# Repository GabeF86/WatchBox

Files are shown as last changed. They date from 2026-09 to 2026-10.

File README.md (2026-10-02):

# WatchBox v0

A prototype watch case that shows your collection's market value on a 16×2 LCD.
A local web app stores your watches and values each one with the Apify valuation engine (eBay sold prices from the last 90 days plus Chrono24 asking prices), falling back to TheWatchAPI or eBay asking prices, and an ESP32 displays them.

## Hardware you need
- ESP32 devkit, I2C LCD1602 (PCF8574 backpack), USB cable and charger
- 4 female-female Dupont jumpers
- LCD: 4× M3 (or M2.5) self-tapping screws, **6 mm max** (longer ones can crack the front face)
- Back plate: 4× M3 × 10–12 mm self-tapping screws
- Double-sided foam tape for the ESP32

## Get a price source key
**Apify valuation engine (default, most accurate):** create a free account at https://apify.com, copy your Personal API token (Console → Settings → API & Integrations) into `server/.env` as `APIFY_TOKEN`. Each watch is valued from eBay sold listings (last 90 days) and Chrono24 asking prices, adjusted for its condition, box & papers and other details, with a backtest that shows how accurate the estimate is. Explain any watch's number by running `.venv/bin/python scripts/check_valuation.py <watch id>` from `server/` (add `--fetch` to pull fresh data first).
After switching to the Apify engine, click **Refresh prices now** once to get the first valuations right away; otherwise they wait for the next scheduled refresh.

**TheWatchAPI (fallback):** register free at https://www.thewatchapi.com/register and put your API token in `server/.env` as `THEWATCHAPI_TOKEN`.
The free plan allows 25 requests a day, so keep `REFRESH_HOURS=24` (8 watches = 8 requests a day, plus one per watch you add or edit).
Their docs say price history may need the Standard plan; if so, the app logs a clear "may need a higher TheWatchAPI plan" error. Check with `scripts/check_price.py` right after you get your token.

**eBay (optional fallback):** used if both `APIFY_TOKEN` and `THEWATCHAPI_TOKEN` are empty.
1. Sign up at https://developer.ebay.com and create a **Production** keyset.
2. When asked about Marketplace Account Deletion notifications, choose the opt-out/exempt option (this app stores no eBay user data).
3. Copy **App ID** → `EBAY_CLIENT_ID` and **Cert ID** → `EBAY_CLIENT_SECRET` in `server/.env`.

## Run the app
```bash
cd server
python3 -m venv .venv && .venv/bin/pip install -r requirements.txt
cp .env.example .env        # add your APIFY_TOKEN (or THEWATCHAPI_TOKEN)
.venv/bin/python -m watchbox
```
Open http://localhost:8000 and add watches. The log prints the `ESP32 SERVER_URL` to put in the firmware config.
On first run macOS asks whether Python may accept incoming network connections: click **Allow**, or the ESP32 can't reach the server.

Check one price by hand: `.venv/bin/python scripts/check_price.py Rolex 126610LN`
Tests: `.venv/bin/pytest -q`

Backups: the database uses SQLite WAL mode, so don't just copy `watchbox.db` while the app is running. Either run `sqlite3 server/watchbox.db ".backup watchbox-backup.db"` (safe while running), or stop the app and copy `watchbox.db` together with its `watchbox.db-wal` and `watchbox.db-shm` files.

## Flash the ESP32
Install arduino-cli (no Homebrew needed) and the ESP32 core once:
```bash
mkdir -p ~/.local/bin && curl -fsSL https://downloads.arduino.cc/arduino-cli/arduino-cli_latest_macOS_ARM64.tar.gz | tar -xz -C ~/.local/bin arduino-cli
alias arduino-cli=~/.local/bin/arduino-cli      # or add ~/.local/bin to PATH
arduino-cli config init --overwrite
arduino-cli config add board_manager.additional_urls https://espressif.github.io/arduino-esp32/package_esp32_index.json
arduino-cli core update-index && arduino-cli core install esp32:esp32
arduino-cli lib install "LiquidCrystal I2C" ArduinoJson
```

Wiring: LCD GND→GND, VCC→5V (labelled VIN on some boards), SDA→GPIO21, SCL→GPIO22. Optional button: GPIO4→GND.
```bash
cp firmware/watchbox_v0/config.example.h firmware/watchbox_v0/config.h   # edit Wi-Fi (2.4 GHz), SERVER_URL, LCD_ADDR
arduino-cli board list                                                    # find the port, e.g. /dev/cu.usbserial-0001
arduino-cli compile --upload -p <port> --fqbn esp32:esp32:esp32 firmware/watchbox_v0
arduino-cli monitor -p <port> -c baudrate=115200
```
Don't know the LCD address? Flash `firmware/i2c_scan` first and watch the serial monitor.

Hardware notes:
- Backlight on but no text: turn the blue contrast potentiometer on the LCD backpack.
- A backpack powered from 5V pulls SDA/SCL up to 5V, but ESP32 pins are 3.3V. It usually works but is out of spec. For a long-running build, power the backpack from 3.3V (re-adjust the contrast pot) or use an I2C level shifter.
- If the LCD shows garbage or the board resets when Wi-Fi starts, the USB supply is too weak: use a better cable or charger.

## Print the enclosure
Download OpenSCAD from https://openscad.org/downloads.html (the macOS development snapshot works on Apple Silicon) and drag it to `/Applications` or `~/Applications`. Edit the measurements at the top of `enclosure/watchbox_v0.scad`, then:
```bash
alias openscad="$HOME/Applications/OpenSCAD.app/Contents/MacOS/OpenSCAD"   # or /Applications/...
openscad -D 'part="front"' -o enclosure/watchbox_v0_front.stl enclosure/watchbox_v0.scad
openscad -D 'part="back"'  -o enclosure/watchbox_v0_back.stl  enclosure/watchbox_v0.scad
```
Front shell face-down, back plate flat with the rail up, no supports. In Bambu Studio, turn on elephant-foot compensation: the front face is the first layer and the window must stay full size.

Before mounting the LCD: the common PCF8574 backpack's 4 header pins stick out sideways past the LCD's short edge and won't fit in the box. Gently bend them 90° toward the back (or solder the wires on directly).
Stick the ESP32 to the rail with its USB end toward the right wall (the USB notch). When closing the box, the tall stop at the rail's other end must point away from the notch.

## Notes
**Apify valuation engine:** each estimate comes from eBay sold prices (last 90 days) blended with Chrono24 asking prices, which are first lowered by the measured asking-to-sold gap. Both are adjusted for your watch's condition and box & papers. The web page shows the breakdown, the confidence and a backtest. On the LCD, a `?` after the price means low confidence. Run `.venv/bin/python scripts/check_valuation.py <watch id>` from `server/` to see every comparable and why it was kept or dropped.

**TheWatchAPI / eBay Browse fallbacks:** these are **asking** prices, not sold prices. TheWatchAPI's data can lag (in Sept 2026 its newest point was 2024-07-17), so the page shows the data date, and the LCD adds the month (e.g. `$12,413 Jul24`) when the data is over 30 days old. The price is TheWatchAPI's latest indicative USD price for the reference number, or (eBay fallback) the median of current eBay listings.

If your exact reference isn't listed, fill in "Price using reference" with a close variant; the price is then marked as an estimate (`~` on the LCD).
The price source is swappable (`server/watchbox/pricing.py` → `PriceProvider`; the engine is `server/watchbox/valuation/`).

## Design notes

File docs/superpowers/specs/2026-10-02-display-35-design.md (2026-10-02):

# WatchBox v1, Part 3: 3.5" Display Firmware: Design

**Date:** 2026-10-02
**Status:** Approved in brainstorming, awaiting spec review
**Builds on:** `2026-10-02-valuation-engine-design.md` (part 1), the server in `server/`, and the bring-up sketch `firmware/board_test_35/`.

## Context

The box's screen is an **ESP32-32E 3.5" board** (LCDwiki/Elecrow E32R35T):
- **Display:** ST7796 panel, 320×480, used in landscape at 480×320.
- **Touch:** XPT2046 resistive, sharing the HSPI bus (SCK 14, MOSI 13, MISO 12); LCD CS 15, DC 2, backlight 27; touch CS 33, touch interrupt 36.
- **Other hardware:** battery sense on ADC 34, and BOOT on IO0.
- **Mounting:** the board sits in the printed lid liner (`enclosure/lid_liner.scad`), behind its window.

Bring-up on 2026-10-02 established the following, which are now requirements:
- **SPI write clock 20 MHz.** At 40 MHz the colors came out garbled.
- **Normal colors:** inversion off, RGB order.
- **Touch calibration** `{378, 3815, 333, 301, 3689, 3781, 3687, 332}`, used with `setRotation(1)`.
- **The LovyanGFX library works.** The bring-up sketch used about 84% of the default 1.3 MB app partition.

## Decisions made in brainstorming

| Topic | Decision |
|---|---|
| Home screen | **A:** large gold total at the top, then a 4 × 2 slot map laid out like the insert |
| Detail screen | **A:** large estimate and confidence, then three figures: eBay sold, Chrono24 asking, accuracy |
| Setup | **A:** box hotspot + QR setup page now; account pairing comes with part 2 |
| Power | **A:** sleep after inactivity, wake on touch; no lid switch for now |
| Rendering | Draw directly with LovyanGFX (no LVGL, no server-rendered images) |

## Goals

1. Show the collection on the 3.5" screen as a slot map with per-watch detail screens, using the valuation engine's data.
2. Let a new owner set up Wi-Fi and the app address from a phone, with no reflashing.
3. Last for days on battery: deep sleep when not in use, and an instant display of cached data on wake.

## Non-goals

Account pairing and QR pairing to an account (part 2), slot presence sensors, a lid switch, price-trend charts, OTA updates, and controls on the box for editing watches.

## 1. Server: `GET /api/box`

The response contains structured data for the 3.5" box. `/api/display` stays unchanged for the 16×2 LCD box.

```json
{
  "generated_at": "2026-10-02T14:00:00+00:00",
  "total_usd": 39130,
  "priced": 4,
  "slots": [
    {"slot": 1, "watch": {
      "id": 1, "name": "Portugieser", "brand": "IWC", "model": "Portugieser Chronograph",
      "reference": "IW371615", "details": "Full set · Excellent",
      "estimate_usd": 6940, "estimated_reference": false, "confidence": "medium",
      "ebay": {"n": 0, "median": null, "p10": null, "p90": null},
      "chrono24": {"n": 37, "median": 6308},
      "accuracy": {"n": 0, "mdape": null},
      "as_of": "2026-10-02T09:14:00+00:00"}},
    {"slot": 5, "watch": null}
  ],
  "unslotted": []
}
```

- **`slots`** always has exactly 8 entries, ordered 1–8. An empty slot has `"watch": null`. Watches without a slot go in `unslotted`, using the same object shape.
- **`name`** is the nickname if set, otherwise the model, as plain text.
- **`details`** is "<box & papers label> · <condition label>", built with the existing `valuation.models.label()`.
- **`reference`** is the watch's own reference. `estimated_reference` is true when `price_reference` is set; the box then prefixes the price with "~".
- **Valuation fields** come from the latest valuation (`db.latest_valuations`). A watch with no valuation, but a v0 price (TheWatchAPI or eBay Browse), reports that price with `confidence: null` and empty eBay, Chrono24 and accuracy blocks. A watch with no price at all has `estimate_usd: null`.
- **`total_usd`** sums the estimates that are present, and **`priced`** counts them. All money values are whole-dollar integers, so the firmware doesn't format decimals.
- Implemented as a pure builder function `build_box_payload(watches, valuations)` in `server/watchbox/box.py`, plus a route in `app.py`.

## 2. Firmware layout: `firmware/watchbox_35/`

| File | Responsibility |
|---|---|
| `watchbox_35.ino` | Entry point, main loop, the screen state machine |
| `board.h` | LovyanGFX device class (pins, 20 MHz, colors, touch calibration) |
| `theme.h` | Colors, fonts, layout constants |
| `data.h/.cpp` | Box data model; fetching `/api/box`; parsing; caching in NVS |
| `screens.h/.cpp` | Drawing: status bar, home, detail, settings, setup, messages |
| `input.h/.cpp` | Touch handling: tap / swipe detection, hit-testing tiles and buttons |
| `power.h/.cpp` | Battery reading, backlight dimming, deep sleep and wake |
| `net.h/.cpp` | Wi-Fi with WiFiManager, the hotspot, settings stored in NVS |

- **Board settings:** `esp32:esp32:esp32` with **`PartitionScheme=huge_app`** (3 MB app, no OTA).
- **Libraries:** LovyanGFX, ArduinoJson 7, WiFiManager (tzapu).
- `config.h` is no longer used.

## 3. Screens (480 × 320, landscape)

**Theme**

| Element | Value |
|---|---|
| Background | #0B0C0E |
| Tile | #16191E |
| Text | #E9E9E9 |
| Muted text | #8B9099 |
| Gold (total, estimates) | #F2C46D |
| Confidence dots | high #5FD18B, medium #E7C160, low #E07A6A, no confidence grey |

Fonts are LovyanGFX FreeSans and FreeSansBold at 9/12/18/24 pt.

**Status bar** (24 px, every screen except setup)
- Left: the title or "‹ Back".
- Right: Wi-Fi indicator (●, or ○ when offline), battery ("82%" or "USB"), "updated h:mm", and a ⚙ icon (tap target 40×24).

**Home**
- **Total row:** the total in gold 24 pt at the left; "N watches · market estimate" muted on the right.
- **Slot map:** a 4 × 2 grid of tiles (about 110 × 100 px, 6 px gaps).
  - A tile with a watch shows the slot number (muted), its name (12 pt, up to 2 lines, ending in "…" if it doesn't fit), and the price (FreeSansBold 12 pt) with its confidence dot.
  - An empty slot is a dashed outline with "Empty".
  - A watch with no price shows "no price yet".
- **Tapping a watch tile** opens its detail screen; tapping an empty tile does nothing.
- **Unslotted watches** count toward the total but have no tile; the settings screen shows how many there are.

**Detail**
- **Status bar:** "‹ Back" on the left, "Slot N of 8" on the right.
- **Body:**
  - A muted line: BRAND · REFERENCE · details.
  - The name (18 pt).
  - The estimate (gold 24 pt bold, "~" prefix if estimated from another reference) plus the confidence dot and word.
  - Three columns:

    | Column | Main figure | Second line |
    |---|---|---|
    | eBay sold · 90 d | median | "N sales · $Xk–$Yk" (p10–p90) |
    | Chrono24 asking | median | "N listings" |
    | Accuracy | "±Z%" | "backtest, N sales" |

  - A column with no data shows "—" and "not enough data".
  - Footer (muted): "Updated <date time> · eBay + Chrono24".
- **Swiping left or right** moves to the next or previous slot that has a watch, wrapping around. Tapping Back, or **30 s with no touch**, returns home.

**Settings (⚙)**
- **Left:** a QR code, 150 px, encoding the app URL, with the label "Open the app on your phone".
- **Right:** Wi-Fi SSID and signal (dBm), app address, battery voltage and %, firmware version, and the count of unslotted watches if there are any.
- **Buttons:**
  - **Re-run setup:** asks for confirmation, then clears the Wi-Fi settings and restarts into setup.
  - **Back.**

**Setup** (no status bar)
- **Title:** "Set up your WatchBox".
- **Left:** a Wi-Fi QR code (`WIFI:T:nopass;S:WatchBox-XXXX;;`). XXXX is the last 4 hex digits of the MAC address.
- **Right:** the steps:
  1. Scan to join WatchBox-XXXX.
  2. The setup page opens. If it doesn't, go to 192.168.4.1.
  3. Choose your Wi-Fi, enter the app address, then save.

**Messages** (a banner under the status bar, or a full screen)
- **Offline:** "Can't reach the app — showing values from <time>". The cached data stays visible.
- **No data yet** (first boot after setup, app unreachable): "Waiting for the app at <url>…".
- **Low battery** (below 10%, on battery power): "Battery low — please charge".

## 4. Setup and network

- **WiFiManager handles the hotspot.**
  - The hotspot is open, named `WatchBox-XXXX`, with a captive portal.
  - The portal has a custom field "App address" (default `http://watchbox.local:8000`, placeholder `http://192.168.1.50:8000`).
  - The portal times out after 10 minutes, then the box restarts and tries again.
- **Storage:** the app address is saved in NVS (`Preferences` namespace `watchbox`, key `server`). WiFiManager stores the Wi-Fi credentials itself.
- **On boot:**
  - With no saved Wi-Fi, the box shows the setup screen and starts the portal. The setup screen is drawn from WiFiManager's AP-mode callback.
  - Otherwise it connects in the background, waiting up to 20 s. If that fails, it falls back to the cached data plus the offline banner, and keeps retrying every 30 s.
  - **Setup starts only on a first boot or "Re-run setup".** A temporary Wi-Fi outage must not drop a configured box into setup.
- **Fetching:** while awake, the box gets `GET <server>/api/box` on wake and then every 60 s.
  - It uses HTTP/1.0, a 3 s connect timeout and a 5 s read timeout.
  - It validates the payload: `slots` must be an array of 8.
  - It caches the raw JSON in NVS (`Preferences` key `box`, up to 6 KB) only after a successful parse.

## 5. Power

- **Dimming and sleep:** after **120 s** with no touch, the backlight dims to 15%. After **15 s more**, the box saves the current screen state and enters **deep sleep** with `esp_sleep_enable_ext0_wakeup(GPIO_NUM_36, 0)`; the XPT2046 interrupt goes low on touch. The backlight is off and Wi-Fi is stopped first.
- **On wake:**
  1. Draw home from the NVS cache in under 1 s.
  2. Connect Wi-Fi and fetch.
  3. Redraw when the new data differs.
  4. The touch that woke the box isn't treated as a tap.
- **Battery:**
  - The voltage is read as `analogReadMilliVolts(34) × 2`. This assumes the board's 1:2 divider; verify it against a multimeter during bring-up.
  - Conversion to %: linear from 3.30 V (0%) to 4.15 V (100%), clamped.
  - A reading under 2.5 V or over 4.5 V means "USB" (no battery fitted or charging artefacts).
  - Below 10% on battery shows the low-battery banner.
- **Plugged-in mode:** with no battery reading (USB), the sleep timer is **10 min** instead of 2 min.

## 6. Error handling

| Situation | Behaviour |
|---|---|
| App unreachable / HTTP error / bad JSON | Keep the cached data; offline banner with the cache time; retry next cycle |
| No cache and no app | "Waiting for the app at <url>…" |
| Wi-Fi lost while awake | ○ icon, auto-reconnect, offline banner after a failed fetch |
| Touch on an empty tile or outside targets | Ignored |
| Name too long for a tile | Wrapped to 2 lines, then "…" |
| NVS write fails | Logged to serial; the display is unaffected |

## 7. Testing

- **Server:** pytest tests for `build_box_payload` and `/api/box`:
  - always 8 slots;
  - empty slots;
  - unslotted watches;
  - a valuation-backed watch with all blocks;
  - a v0-price fallback;
  - no price at all;
  - the estimated-reference flag;
  - totals and integer rounding.
- **Firmware:** must compile with no warnings from our code. A small `formatPrice` / `truncate` helper set lives in a header with no hardware dependencies.
- **Hands-on acceptance on the owner's board:**
  1. Fresh setup through the hotspot from a phone.
  2. The home screen shows all 4 watches and empty slots 5–8.
  3. Tapping a tile opens its detail.
  4. Swiping moves between watches.
  5. The screen returns home after 30 s.
  6. Settings shows the QR code, and it opens the app.
  7. With the Mac app stopped, the offline banner shows with cached values.
  8. After 2 minutes the screen dims and the box sleeps; a touch wakes it with an instant cached display.
  9. "Re-run setup" works.

## Known limitations

- **Battery calibration:** the divider ratio is assumed and must be checked once.
- **Lid detection:** with no lid switch, the box sleeps on inactivity and not when the lid closes.
- **"watchbox.local" default:** the default app address assumes the Mac app is reachable by that name. Until mDNS is added to the server, the owner enters the Mac's IP address on the setup page.

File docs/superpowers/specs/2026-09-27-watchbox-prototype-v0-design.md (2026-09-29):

# Watch Box Prototype v0: Design

> **Update 2026-09-28:** TheWatchAPI (thewatchapi.com) is now the default price source. See "Price source: TheWatchAPI" at the end. The eBay provider below stays as a fallback. The default refresh is now every 24 h to fit TheWatchAPI's free plan (25 requests a day).

**Date:** 2026-09-27
**Status:** Approved (brainstorming), awaiting spec review

## Context

The long-term product is a smart watch case: a 3D-printed heavy-duty case (about 250 × 205 mm) with an 8-slot insert (4 × 2 grid, slots about 55 × 85 mm, 42 mm deep). A 3.5" color screen inside the lid shows the live market value of the watches currently in the box. Each slot has a presence sensor, owners assign watches to numbered slots on a mobile-friendly website, and a watch's value counts only while its slot detects it. The box runs on a built-in LiPo with USB-C charging, pairs through a setup hotspot and a 6-digit code, and fetches ready-made screen data from a server. The server pulls prices from a licensed provider (WatchCharts) through a swappable price-provider layer.

**v0 is a much smaller first step** that proves the core loop with parts already on hand:
enter watches → fetch real market prices → show them on a screen in the box.

## Goals

1. Enter watches (brand, model, reference, slot 1–8, optional nickname) in a local web app.
2. Fetch a market price per watch from the eBay Browse API automatically.
3. Show the total and each watch's price on the kit's 16×2 I2C LCD, driven by the kit's ESP32.
4. House the ESP32 and LCD in a 3D-printed standalone enclosure (Bambu Studio).

## Non-goals (v0)

Slot presence sensors, battery power, the 3.5" color screen, user accounts or login, cloud hosting, pairing flow, lid-mounted panel, WatchCharts integration.

## Architecture

```
┌──────────────── Mac (same Wi-Fi) ────────────────┐        ┌──── ESP32 + LCD1602 ────┐
│  FastAPI app  ──  SQLite (watches, prices)       │        │  every 60 s:            │
│   ├─ web UI: add/edit/delete watches             │◄───────┤  GET /api/display       │
│   ├─ scheduler: refresh prices every 6 h         │  JSON  │  cycle lines every 4 s  │
│   └─ PriceProvider ── EbayBrowseProvider ──► eBay│        └─────────────────────────┘
└──────────────────────────────────────────────────┘
```

The box asks the server for ready-to-show data, and the server owns all logic and secrets. This matches the final product's architecture, so moving the server to the cloud later is a deployment change.

## Components

### 1. Server app (`server/`): Python 3.13, FastAPI, SQLite

**Data model**
- `watches`: id, brand, model, reference, slot (1–8, unique, nullable), nickname (nullable), created_at
- `prices`: id, watch_id, price_usd (numeric), sample_size (int), source (`"ebay"`), fetched_at. History is kept, and the latest row is the current price.

**Web UI** (server-rendered HTML, mobile-friendly, no JS framework)
- List of watches: slot, display name, current price, "fetched X ago", sample size.
- Add/edit form and delete button.
- "Refresh prices now" button.
- Collection total at the top.

**Price provider layer**
- Interface: `PriceProvider.get_price(brand, reference) -> PriceResult | None`, where `PriceResult` holds `price_usd`, `sample_size` and `source`.
- `EbayBrowseProvider`:
  - Authenticates with an OAuth client-credentials token (scope `https://api.ebay.com/oauth/api_scope`), cached until it expires.
  - Calls `GET /buy/browse/v1/item_summary/search` with `q="<brand> <reference>"`, `category_ids=31387` (Wristwatches), `filter=buyingOptions:{FIXED_PRICE},price:[500..],priceCurrency:USD`, `limit=100`.
  - Keeps only listings whose title contains the reference number, ignoring case, spaces and punctuation (so `126610 LN` matches `126610LN`).
  - Drops titles containing junk phrases (`box only`, `papers only`, `empty box`, `strap only`, `bracelet only`, `band only`, `links only`, `dial only`, `bezel only`, `bezel insert`, `crown only`, `case back`, `for parts`, `parts only`, `for repair`, `needs repair`, `repair only`, `homage`, `replica`, `instruction manual`, `manual only`, `booklet`). These are phrases, not single words, so normal titles like "Ceramic Bezel", "Oyster bracelet", or "Manual Wind" are kept.
  - Editing a watch's brand or reference clears its price history, so a stale price for the old reference is never shown.
  - Removes outliers outside [0.5 × median, 2 × median] of the remaining prices, then returns the median of what's left.
  - Returns `None` when fewer than 3 listings survive, and the UI shows "no price yet" (the server log records why).
- Only `USD` prices are used, and the value is the median **asking** price, labeled as such in the UI.

**Scheduler**
- Refreshes all watches on startup if the newest price is older than 6 h, then every 6 h (APScheduler or an asyncio loop).
- A new or edited watch is priced immediately.
- On eBay errors: log, keep the last good price, and retry at the next cycle.

**Display endpoint:** `GET /api/display`
```json
{
  "generated_at": "2026-09-27T14:00:00Z",
  "screens": [
    {"line1": "TOTAL 7 watches", "line2": "$84,250"},
    {"line1": "1 Submariner", "line2": "$13,400"},
    {"line1": "3 Nautilus 5711", "line2": "no price yet"}
  ]
}
```
- Every `line1` and `line2` is at most 16 ASCII characters, truncated server-side. Watches are ordered by slot, with unslotted watches last and no slot prefix.
- Display name: nickname if set, otherwise the model, prefixed with `"<slot> "`.
- Prices are formatted `$13,400`, whole dollars. `$1.2M` is used if the value exceeds 9 characters.
- An empty collection returns `screens: [{"line1": "No watches yet", "line2": "Add on the app"}]`.
- The total counts only watches that have a price. `line1` shows `TOTAL <n> watches`, where n is the number of priced watches.

**Config** (`server/.env`, gitignored): `EBAY_CLIENT_ID`, `EBAY_CLIENT_SECRET`, `REFRESH_HOURS=6`, `PORT=8000`. The app binds to `0.0.0.0` so the ESP32 can reach it on the LAN.

### 2. Firmware (`firmware/`): Arduino C++, built and flashed with arduino-cli

- Board: ESP32-WROOM-32E dev board (`esp32:esp32:esp32`).
- Libraries: `LiquidCrystal_I2C`, `ArduinoJson` (v7), `WiFi`, `HTTPClient`.
- Wiring: LCD VCC→5V (VIN), GND→GND, SDA→GPIO21, SCL→GPIO22. Optional push-button GPIO4→GND (internal pull-up), which skips to the next screen and forces an immediate re-fetch.
- `config.h` (gitignored, with `config.example.h` committed): `WIFI_SSID`, `WIFI_PASS`, `SERVER_URL` (for example `http://192.168.1.50:8000`), `LCD_ADDR` (default `0x27`).
- Behavior:
  - Boot: LCD shows `WatchBox v0` / `WiFi...` until connected.
  - Fetches `/api/display` on boot, then every 60 s.
  - Cycles through `screens`, one every 4 s.
  - If a fetch fails, it keeps showing the last good screens, and every 3rd screen is `Server offline` / `retrying...`. If it has never had data, it shows only that.
  - Reconnects to Wi-Fi automatically if dropped.
- A separate `firmware/i2c_scan/` sketch prints the LCD's I2C address to serial, for first-time bring-up.

### 3. Enclosure (`enclosure/`): OpenSCAD, exported to STL

- Two parts:
  - `front_shell`: front face with the LCD window, 4 LCD screw posts, 4 corner screw bosses, a USB notch open at the back edge, and an optional button hole in the top wall. It prints front-face-down.
  - `back_plate`: screw holes, vent slots, and a raised center rail (18 mm) that holds the ESP32 with foam tape. The rail sits between the two pin rows, so the Dupont jumpers stay attached underneath. It prints flat.
- Parametric: every part dimension is a variable at the top of `watchbox_v0.scad`. Defaults:
  - LCD1602 PCB 80 × 36 mm, mounting holes 75 × 31 mm (M3), visible area 64.5 × 16 mm, module depth with I2C backpack about 20 mm.
  - ESP32 board 55 × 28 mm (38-pin devkit). **Measure your board and update these values before printing.**
  - Wall 2 mm, clearance 0.3 mm.
- Prints flat without supports on the Bambu bed, in PLA or PETG. Closes with M3 screws, or M2.5 self-tapping into the bosses.
- OpenSCAD is installed with Homebrew (`brew install --cask openscad`). STLs are exported from the command line.

## Error handling summary

| Failure | Behavior |
|---|---|
| eBay auth or API error | Log it, keep the last price, retry next cycle. UI shows "fetched X ago". |
| Fewer than 3 usable listings | No new price stored. UI shows "no price yet" (same as never fetched; the server log records which), LCD shows `no price yet`. |
| Mac or server unreachable | LCD keeps the last data and shows a `Server offline` screen now and then. |
| Wi-Fi drops | Firmware reconnects and shows `WiFi...` while down. |
| Empty collection | `No watches yet` / `Add on the app`. |

## Testing

- **Server:** pytest suite using saved eBay JSON fixtures, with no live calls: junk filtering, outlier removal, median, the fewer-than-3 rule, 16-character formatting and truncation, price formatting (`$13,400`, `$1.2M`), `/api/display` ordering and empty state, and CRUD endpoints.
- **Manual eBay check:** a script prints the chosen price and the listings kept for one reference, to sanity-check the results.
- **Firmware:** the I2C scan sketch, then the full sketch pointed at the server. Check the offline behavior by stopping the server.
- **End to end:** add a watch in the UI and confirm it appears on the LCD within 60 s.

## User actions required

1. Create an eBay developer account, create a Production keyset, and choose the opt-out for marketplace account deletion notifications (the app stores no eBay user data). Put the keys in `server/.env`.
2. Measure the ESP32 board and update the enclosure parameters.
3. Wire 4 jumpers (plus an optional button), flash the board, and print 2 parts.

## Later (not v0)

Slot sensors (IR in the slot wall vs FSR under the pillow, tested in the insert), 3.5" ESP32-S3 display board, LiPo and charging, cloud deployment and accounts, pairing, WatchCharts provider, lid-mounted housing.

## Price source: TheWatchAPI (added 2026-09-28)

- `TheWatchApiProvider` calls `GET https://api.thewatchapi.com/v1/reference/price/history` with `api_token`, `reference_number` and `date_from` (today minus 30 days). It uses the newest data point's `price` (indicative USD asking price). `sample_size` stores the number of data points, and the UI hides the "N listings" text for this source.
- If the response's `meta.brand` doesn't match the watch's brand (ignoring case, accents and punctuation), no price is stored, because reference numbers can collide across brands.
- Empty data means no price is stored, and the UI and LCD show "no price yet".
- Non-200 responses raise `WatchApiError` with the API's error code and message. A 402 or 403 adds a hint that price history may need a higher plan. The token is a query parameter, so it never appears in error messages, and the `httpx` logger is set to WARNING so request URLs aren't logged.
- Config: `THEWATCHAPI_TOKEN`, and `PRICE_SOURCE=auto|thewatchapi|ebay`. `auto` prefers TheWatchAPI when its token is set, otherwise eBay. `REFRESH_HOURS` now defaults to 24.
- `scripts/check_price.py` uses whichever source is configured. For TheWatchAPI it prints the last 30 days of data points and the chosen price.
- Open question: TheWatchAPI's pricing page says historical prices are on every plan, including free, while its documentation says price endpoints need "Standard plan and above". Confirm with a real free token.

### Update 2026-09-29: dated prices

- With a paid plan, TheWatchAPI's newest price point for every tested reference was **2024-07-17**, so a 30-day window returned nothing. The provider now requests the full history (no `date_from`) and uses the newest point, storing its date as `prices.price_date` (`PriceResult.as_of`). Older databases get the column added on connect.
- The web page shows "data from YYYY-MM-DD". On the LCD, when the data is over 30 days old, line 2 becomes `<price> <MonYY>`, for example `$12,413 Jul24`, if it fits in 16 characters.

### Update 2026-09-29: estimated prices via a close reference

- Watches have an optional `price_reference`. When it's set, prices are looked up under it instead of the real `reference`. This is for references the price source doesn't list, for example Glashütte 2-39-47-01-01-04 priced from 2-39-47-06-02-04.
- Such prices are marked as estimates: the web page shows "estimated from <ref>", and the LCD prefixes the price with `~` (for example `~$6,779 Jul24`). Changing `price_reference` clears the watch's price history, the same as changing brand or reference. Older databases get the column added on connect.

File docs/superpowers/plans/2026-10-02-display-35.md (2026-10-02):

# 3.5" Display Firmware Implementation Plan

> **For agentic workers:** REQUIRED SUB-SKILL: Use superpowers:subagent-driven-development (recommended) or superpowers:executing-plans to implement this plan task-by-task. Steps use checkbox (`- [ ]`) syntax for tracking.

**Goal:** Firmware for the ESP32-32E 3.5" board that shows the collection as a slot map with per-watch detail screens, a settings screen and a hotspot setup flow, and sleeps between uses. It is fed by a new server endpoint, `GET /api/box`.

**Architecture:**
- **Server:** a pure builder, `server/watchbox/box.py`, turns watches and their latest valuations into box-ready JSON. Strings are ASCII, money is whole dollars, and time labels are local.
- **Firmware:** `firmware/watchbox_35/` is split into small modules: board, theme, format, data, screens, input, power and net. The `.ino` holds the screen state machine.
- **Libraries:** drawing uses LovyanGFX, setup uses WiFiManager, and caching uses NVS `Preferences`.

**Tech Stack:** Python 3.13, FastAPI, pytest · Arduino C++ on esp32 core 3.3.12 via `~/.local/bin/arduino-cli` · LovyanGFX 1.2.30, ArduinoJson 7, WiFiManager (tzapu).

**Spec:** `docs/superpowers/specs/2026-10-02-display-35-design.md`

**Conventions:**
- Run commands from the repo root.
- Commit messages end with a blank line and `Co-Authored-By: Claude Opus 5.5 <noreply@anthropic.com>`.
- Steps marked **[CONTROLLER]** need the physical board and the owner, so subagents don't run them.
- Never open `server/watchbox.db`: it's the owner's real data.

**Board facts (verified 2026-10-02):** SPI write clock 20 MHz (40 MHz garbles colors), `invert=false`, `rgb_order=false`, `setRotation(1)`, touch calibration `{378, 3815, 333, 301, 3689, 3781, 3687, 332}`. The board's serial port is usually `/dev/cu.usbserial-110`.

**Implementation choices that refine the spec (Task 4 records them in the spec):**
- The payload adds `updated_label` (top level) and `as_of_label` (per watch). These are local-time strings such as `"Oct 2, 1:14 PM"`, so the box needs no clock.
- All strings sent to the box are ASCII-folded (Glashütte → Glashutte), because the GFX fonts are ASCII-only.
- `details` uses short labels: "Full set, Excellent".
- On screen, ASCII stand-ins replace symbols: "< Back", a three-line menu icon instead of ⚙, "+/-" instead of ±, and "-" instead of "·".
- Tile names use 9 pt, so about 12 characters fit per line.
- Waking from sleep always shows the home screen.

---

## File map

```
server/watchbox/box.py            build_box_payload(), local_label(), ascii()
server/watchbox/app.py            + GET /api/box
server/tests/test_box.py
firmware/watchbox_35/
  watchbox_35.ino                 state machine: Home / Detail / Settings / ConfirmReset
  board.h                         LGFX device class, TOUCH_CAL, extern tft
  theme.h                         colors (RGB565), layout constants
  format.h                        formatPrice(), formatK()
  data.h / data.cpp               BoxData, parseBox(), fetchBox(), save/loadCache()
  screens.h / screens.cpp         all drawing + hit areas
  input.h / input.cpp             tap / swipe detection
  power.h / power.cpp             battery, dimming, deep sleep
  net.h / net.cpp                 WiFiManager setup, saved server, reconnect
```

---

### Task 1: Server `GET /api/box`

**Files:**
- Create: `server/watchbox/box.py`
- Modify: `server/watchbox/app.py`
- Test: `server/tests/test_box.py`

- [ ] **Step 1: Write the failing tests** in `server/tests/test_box.py`:

```python
from datetime import timezone

from fastapi.testclient import TestClient

from watchbox import db
from watchbox.app import create_app
from watchbox.box import ascii, build_box_payload, local_label
from watchbox.config import Settings
from watchbox.db import Watch

UTC = timezone.utc
NOW = "2026-10-02T14:00:00+00:00"

def watch(id, slot, **kw):
    return Watch(id=id, brand=kw.pop("brand", "Rolex"), model=kw.pop("model", "Submariner Date"),
                 reference=kw.pop("reference", "116610LN"), slot=slot, nickname=kw.pop("nickname", None), **kw)

def val(**kw):
    base = dict(estimate_usd=11720.4, confidence="high", n_ebay=30, ebay_median=11550.0, ebay_p10=10490.4,
                ebay_p90=12793.0, n_c24=38, c24_median=12656.0, backtest_n=30, backtest_mdape=0.0372,
                as_of="2026-10-02T13:14:00+00:00")
    return base | kw

def test_local_label_and_ascii():
    assert local_label("2026-10-02T13:14:00+00:00", UTC) == "Oct 2, 1:14 PM"
    assert local_label("2026-10-02T00:05:00+00:00", UTC) == "Oct 2, 12:05 AM"
    assert local_label(None, UTC) == ""
    assert ascii("Glashütte Original") == "Glashutte Original"

def test_always_eight_slots_with_empty_ones_null():
    p = build_box_payload([watch(1, 4)], {1: val()}, NOW, tz=UTC)
    assert [s["slot"] for s in p["slots"]] == list(range(1, 9))
    assert p["slots"][3]["watch"]["name"] == "Submariner Date"
    assert all(p["slots"][i]["watch"] is None for i in (0, 1, 2, 4, 5, 6, 7))
    assert p["generated_at"] == NOW

def test_valuation_fields_are_whole_dollars_with_labels():
    w = build_box_payload([watch(1, 4, nickname="Sub")], {1: val()}, NOW, tz=UTC)["slots"][3]["watch"]
    assert (w["name"], w["model"], w["estimate_usd"], w["confidence"]) == ("Sub", "Submariner Date", 11720, "high")
    assert w["ebay"] == {"n": 30, "median": 11550, "p10": 10490, "p90": 12793}
    assert w["chrono24"] == {"n": 38, "median": 12656}
    assert w["accuracy"] == {"n": 30, "mdape": 0.0372}
    assert w["as_of_label"] == "Oct 2, 1:14 PM"
    assert w["details"] == "Full set, Excellent"
    assert w["estimated_reference"] is False

def test_v0_price_fallback_and_no_price():
    old = watch(1, 1, price_usd=12412.6, fetched_at="2026-10-01T09:00:00+00:00")
    p = build_box_payload([old, watch(2, 2)], {}, NOW, tz=UTC)
    a, b = p["slots"][0]["watch"], p["slots"][1]["watch"]
    assert a["estimate_usd"] == 12413 and a["confidence"] is None
    assert a["ebay"] == {"n": 0, "median": None, "p10": None, "p90": None}
    assert a["accuracy"] == {"n": 0, "mdape": None} and a["as_of_label"] == "Oct 1, 9:00 AM"
    assert b["estimate_usd"] is None
    assert (p["total_usd"], p["priced"]) == (12413, 1)

def test_unslotted_watches_count_toward_the_total_and_are_ascii():
    gs = watch(1, None, brand="Glashütte Original", model="Sixties", reference="2-39-47-01-01-04",
               price_reference="2-39-47-06-02-04", box_papers="watch_only", condition="very_good")
    p = build_box_payload([gs], {1: val(estimate_usd=6820.0, confidence="medium")}, NOW, tz=UTC)
    u = p["unslotted"][0]
    assert u["brand"] == "Glashutte Original" and u["estimated_reference"] is True
    assert u["details"] == "Watch only, Very good"
    assert (p["total_usd"], p["priced"]) == (6820, 1)
    assert all(s["watch"] is None for s in p["slots"])

def test_updated_label_is_the_newest_data():
    vals = {1: val(as_of="2026-10-01T09:00:00+00:00"), 2: val(as_of="2026-10-02T13:14:00+00:00")}
    p = build_box_payload([watch(1, 1), watch(2, 2)], vals, NOW, tz=UTC)
    assert p["updated_label"] == "Oct 2, 1:14 PM"
    assert build_box_payload([], {}, NOW, tz=UTC)["updated_label"] == ""

def test_api_box_endpoint(tmp_path):
    path = str(tmp_path / "t.db")
    conn = db.connect(path)
    db.add_watch(conn, "Rolex", "Submariner Date", "116610LN", 4, None)
    conn.close()
    settings = Settings(ebay_client_id="", ebay_client_secret="", refresh_hours=24, db_path=path)
    with TestClient(create_app(settings, None, run_scheduler=False)) as c:
        body = c.get("/api/box").json()
    assert len(body["slots"]) == 8 and body["slots"][3]["watch"]["reference"] == "116610LN"
```

- [ ] **Step 2: Run to verify failure**

Run: `server/.venv/bin/pytest server/tests/test_box.py -q`
Expected: FAIL, `ModuleNotFoundError: No module named 'watchbox.box'`

- [ ] **Step 3: Implement `server/watchbox/box.py`**

```python
"""Structured collection data for the 3.5" display box (GET /api/box).

Everything is ready to draw: ASCII strings (the box's fonts have no accents), whole-dollar integers, and
local-time labels (the box has no clock).
"""
import unicodedata
from datetime import datetime, timezone, tzinfo

from .db import Watch
from .valuation.models import label

SLOT_COUNT = 8
BOX_SHORT = {"full_set": "Full set", "box_only": "Box only", "papers_only": "Papers only", "watch_only": "Watch only"}

def ascii(text: str | None) -> str:
    return unicodedata.normalize("NFKD", text or "").encode("ascii", "ignore").decode()

def local_label(iso: str | None, tz: tzinfo | None = None) -> str:
    """'Oct 2, 1:14 PM' in the server's local time (or `tz`)."""
    if not iso:
        return ""
    t = datetime.fromisoformat(iso)
    if t.tzinfo is None:
        t = t.replace(tzinfo=timezone.utc)
    t = t.astimezone(tz)
    return f"{t.strftime('%b')} {t.day}, {t.hour % 12 or 12}:{t.minute:02d} {'AM' if t.hour < 12 else 'PM'}"

def _money(value: float | None) -> int | None:
    return None if value is None else int(value + 0.5)

def _watch(w: Watch, v: dict | None, tz: tzinfo | None) -> dict:
    as_of = v["as_of"] if v else w.fetched_at
    return {
        "id": w.id,
        "name": ascii(w.nickname or w.model),
        "brand": ascii(w.brand),
        "model": ascii(w.model),
        "reference": ascii(w.reference),
        "details": f"{BOX_SHORT.get(w.box_papers, label(w.box_papers))}, {label(w.condition)}",
        "estimate_usd": _money(v["estimate_usd"] if v else w.price_usd),
        "estimated_reference": bool(w.price_reference),
        "confidence": v["confidence"] if v else None,
        "ebay": {"n": v["n_ebay"] if v else 0, "median": _money(v["ebay_median"] if v else None),
                 "p10": _money(v["ebay_p10"] if v else None), "p90": _money(v["ebay_p90"] if v else None)},
        "chrono24": {"n": v["n_c24"] if v else 0, "median": _money(v["c24_median"] if v else None)},
        "accuracy": {"n": v["backtest_n"] if v else 0,
                     "mdape": round(v["backtest_mdape"], 4) if v and v["backtest_mdape"] is not None else None},
        "as_of": as_of,
        "as_of_label": local_label(as_of, tz),
    }

def build_box_payload(watches: list[Watch], valuations: dict[int, dict], generated_at: str,
                      tz: tzinfo | None = None) -> dict:
    entries = {w.id: _watch(w, valuations.get(w.id), tz) for w in watches}
    by_slot = {w.slot: entries[w.id] for w in watches if w.slot is not None}
    priced = [e for e in entries.values() if e["estimate_usd"] is not None]
    newest = max((e["as_of"] for e in priced if e["as_of"]), default=None)
    return {
        "generated_at": generated_at,
        "total_usd": sum(e["estimate_usd"] for e in priced),
        "priced": len(priced),
        "updated_label": local_label(newest, tz),
        "slots": [{"slot": n, "watch": by_slot.get(n)} for n in range(1, SLOT_COUNT + 1)],
        "unslotted": [entries[w.id] for w in watches if w.slot is None],
    }
```

- [ ] **Step 4: Add the route.** In `server/watchbox/app.py`, add `from .box import build_box_payload` with the other local imports. Then, directly after the existing `@app.get("/api/display")` handler, add:

```python
    @app.get("/api/box")
    def box(conn: Conn):
        return build_box_payload(db.list_watches(conn), db.latest_valuations(conn), db.now_iso())
```

- [ ] **Step 5: Run to verify pass**

Run: `server/.venv/bin/pytest server/tests -q`
Expected: all pass (286 + 7 = 293).

- [ ] **Step 6: Commit**

```bash
git add server/watchbox/box.py server/watchbox/app.py server/tests/test_box.py
git commit -m "feat: /api/box structured payload for the 3.5\" display"
```

---

### Task 2: Firmware foundation (board, theme, format) and libraries

**Files:**
- Create: `firmware/watchbox_35/board.h`, `firmware/watchbox_35/theme.h`, `firmware/watchbox_35/format.h`
- Create (temporary, replaced in Task 3): `firmware/watchbox_35/watchbox_35.ino`

- [ ] **Step 1: Install libraries**

```bash
~/.local/bin/arduino-cli lib install WiFiManager
~/.local/bin/arduino-cli lib list | grep -E "LovyanGFX|ArduinoJson|WiFiManager"
```
Expected: all three are listed. LovyanGFX and ArduinoJson are already installed.

- [ ] **Step 2: Create `firmware/watchbox_35/board.h`**

```cpp
#pragma once
// ESP32-32E 3.5" board: ST7796 320x480 + XPT2046 touch on HSPI. Values verified on the owner's board.
#define LGFX_USE_V1
#include <LovyanGFX.hpp>

class LGFX : public lgfx::LGFX_Device {
  lgfx::Panel_ST7796 panel_;
  lgfx::Bus_SPI bus_;
  lgfx::Light_PWM light_;
  lgfx::Touch_XPT2046 touch_;

 public:
  LGFX() {
    {
      auto cfg = bus_.config();
      cfg.spi_host = HSPI_HOST;
      cfg.spi_mode = 0;
      cfg.freq_write = 20000000;  // 40 MHz garbles colors on this panel
      cfg.freq_read = 16000000;
      cfg.spi_3wire = false;
      cfg.use_lock = true;
      cfg.dma_channel = SPI_DMA_CH_AUTO;
      cfg.pin_sclk = 14;
      cfg.pin_mosi = 13;
      cfg.pin_miso = 12;
      cfg.pin_dc = 2;
      bus_.config(cfg);
      panel_.setBus(&bus_);
    }
    {
      auto cfg = panel_.config();
      cfg.pin_cs = 15;
      cfg.pin_rst = -1;  // shared with the ESP32 EN line
      cfg.pin_busy = -1;
      cfg.panel_width = 320;
      cfg.panel_height = 480;
      cfg.readable = true;
      cfg.invert = false;
      cfg.rgb_order = false;
      cfg.bus_shared = true;
      panel_.config(cfg);
    }
    {
      auto cfg = light_.config();
      cfg.pin_bl = 27;
      cfg.invert = false;
      cfg.freq = 44100;
      cfg.pwm_channel = 7;
      light_.config(cfg);
      panel_.setLight(&light_);
    }
    {
      auto cfg = touch_.config();
      cfg.x_min = 300;
      cfg.x_max = 3900;
      cfg.y_min = 200;
      cfg.y_max = 3900;
      cfg.pin_int = 36;
      cfg.bus_shared = true;
      cfg.spi_host = HSPI_HOST;
      cfg.freq = 1000000;
      cfg.pin_sclk = 14;
      cfg.pin_mosi = 13;
      cfg.pin_miso = 12;
      cfg.pin_cs = 33;
      touch_.config(cfg);
      panel_.setTouch(&touch_);
    }
    setPanel(&panel_);
  }
};

extern LGFX tft;

// Measured on the owner's board with setRotation(1) (BOOT-held calibration, 2026-10-02).
static uint16_t TOUCH_CAL[8] = {378, 3815, 333, 301, 3689, 3781, 3687, 332};
```

- [ ] **Step 3: Create `firmware/watchbox_35/theme.h`**

```cpp
#pragma once
#include <stdint.h>

constexpr uint16_t rgb(uint8_t r, uint8_t g, uint8_t b) {
  return ((r & 0xF8) << 8) | ((g & 0xFC) << 3) | (b >> 3);
}

namespace theme {
constexpr uint16_t BG = rgb(0x0B, 0x0C, 0x0E);
constexpr uint16_t TILE = rgb(0x16, 0x19, 0x1E);
constexpr uint16_t TEXT = rgb(0xE9, 0xE9, 0xE9);
constexpr uint16_t MUTED = rgb(0x8B, 0x90, 0x99);
constexpr uint16_t LINE = rgb(0x2A, 0x2E, 0x35);
constexpr uint16_t GOLD = rgb(0xF2, 0xC4, 0x6D);
constexpr uint16_t CONF_HIGH = rgb(0x5F, 0xD1, 0x8B);
constexpr uint16_t CONF_MEDIUM = rgb(0xE7, 0xC1, 0x60);
constexpr uint16_t CONF_LOW = rgb(0xE0, 0x7A, 0x6A);
constexpr uint16_t NONE = rgb(0x55, 0x5A, 0x62);
constexpr uint16_t WARN_BG = rgb(0x3A, 0x2E, 0x12);
constexpr uint16_t BUTTON = rgb(0x24, 0x28, 0x30);
constexpr uint16_t WHITE = rgb(0xFF, 0xFF, 0xFF);

constexpr int W = 480, H = 320, BAR_H = 24, MARGIN = 10, GAP = 6;
constexpr int GRID_TOP = 80;
constexpr int TILE_W = (W - 2 * MARGIN - 3 * GAP) / 4;     // 110
constexpr int TILE_H = (H - GRID_TOP - MARGIN - GAP) / 2;  // 112
}  // namespace theme
```

- [ ] **Step 4: Create `firmware/watchbox_35/format.h`**

```cpp
#pragma once
#include <Arduino.h>

// "$13,650"; from a million up "$1.2M".
inline String formatPrice(long usd) {
  if (usd >= 1000000) {
    char buf[16];
    snprintf(buf, sizeof buf, "$%.1fM", usd / 1000000.0);
    return String(buf);
  }
  String digits = String(usd);
  String out = "$";
  int n = digits.length();
  for (int i = 0; i < n; i++) {
    out += digits[i];
    int rest = n - 1 - i;
    if (rest > 0 && rest % 3 == 0) out += ',';
  }
  return out;
}

// "$10.5k" for compact ranges; under $1,000 stays "$950".
inline String formatK(long usd) {
  if (usd < 1000) return "$" + String(usd);
  char buf[16];
  snprintf(buf, sizeof buf, "$%.1fk", usd / 1000.0);
  return String(buf);
}
```

- [ ] **Step 5: Temporary `firmware/watchbox_35/watchbox_35.ino`** (replaced in Task 3) to prove the foundation compiles:

```cpp
#include "board.h"
#include "format.h"
#include "theme.h"

LGFX tft;

void setup() {
  tft.init();
  tft.setRotation(1);
  tft.fillScreen(theme::BG);
  tft.setTextColor(theme::GOLD);
  tft.setFont(&fonts::FreeSansBold24pt7b);
  tft.drawString(formatPrice(39130).c_str(), 20, 20);
}

void loop() {}
```

- [ ] **Step 6: Compile**

Run: `~/.local/bin/arduino-cli compile --fqbn esp32:esp32:esp32:PartitionScheme=huge_app firmware/watchbox_35 2>&1 | grep -E "error|Sketch uses"`
Expected: a `Sketch uses … (…%) of program storage space. Maximum is 3145728 bytes.` line, and no errors.

- [ ] **Step 7: Commit**

```bash
git add firmware/watchbox_35
git commit -m "feat: 3.5\" firmware foundation (board, theme, format)"
```

---

### Task 3: Firmware modules and state machine

**Files:**
- Create: `firmware/watchbox_35/data.h`, `data.cpp`, `screens.h`, `screens.cpp`, `input.h`, `input.cpp`, `power.h`, `power.cpp`, `net.h`, `net.cpp`
- Replace: `firmware/watchbox_35/watchbox_35.ino`

- [ ] **Step 1: `firmware/watchbox_35/data.h`**

```cpp
#pragma once
#include <Arduino.h>

struct WatchInfo {
  bool present = false;
  int slot = 0;
  String name, brand, reference, details, confidence, asOf;
  bool hasEstimate = false;
  long estimate = 0;
  bool estimatedRef = false;
  int ebayN = 0;
  bool hasEbay = false;
  long ebayMedian = 0, ebayP10 = 0, ebayP90 = 0;
  int c24N = 0;
  bool hasC24 = false;
  long c24Median = 0;
  int accN = 0;
  bool hasAcc = false;
  float mdape = 0;
};

struct BoxData {
  bool valid = false;
  long total = 0;
  int priced = 0;
  int unslotted = 0;
  String updated;  // "Oct 2, 1:14 PM", from the server
  WatchInfo slots[8];
};

bool parseBox(const String& json, BoxData& out);     // false if not a valid 8-slot payload
bool fetchBox(const String& server, String& json);   // true on HTTP 200 with a body
void saveCache(const String& json);
bool loadCache(String& json);
```

- [ ] **Step 2: `firmware/watchbox_35/data.cpp`**

```cpp
#include "data.h"

#include <ArduinoJson.h>
#include <HTTPClient.h>
#include <Preferences.h>

#include <memory>

namespace {
const char* NS = "watchbox";
const size_t MAX_CACHE = 6000;

void readWatch(JsonObjectConst w, int slot, WatchInfo& out) {
  out = WatchInfo();
  out.present = true;
  out.slot = slot;
  out.name = w["name"] | "";
  out.brand = w["brand"] | "";
  out.reference = w["reference"] | "";
  out.details = w["details"] | "";
  out.confidence = w["confidence"] | "";
  out.asOf = w["as_of_label"] | "";
  out.hasEstimate = !w["estimate_usd"].isNull();
  out.estimate = w["estimate_usd"] | 0L;
  out.estimatedRef = w["estimated_reference"] | false;
  JsonObjectConst e = w["ebay"];
  out.ebayN = e["n"] | 0;
  out.hasEbay = !e["median"].isNull();
  out.ebayMedian = e["median"] | 0L;
  out.ebayP10 = e["p10"] | 0L;
  out.ebayP90 = e["p90"] | 0L;
  JsonObjectConst c = w["chrono24"];
  out.c24N = c["n"] | 0;
  out.hasC24 = !c["median"].isNull();
  out.c24Median = c["median"] | 0L;
  JsonObjectConst a = w["accuracy"];
  out.accN = a["n"] | 0;
  out.hasAcc = !a["mdape"].isNull();
  out.mdape = a["mdape"] | 0.0f;
}
}  // namespace

bool parseBox(const String& json, BoxData& out) {
  JsonDocument doc;
  if (deserializeJson(doc, json)) return false;
  JsonArrayConst slots = doc["slots"];
  if (slots.isNull() || slots.size() != 8) return false;
  BoxData fresh;
  fresh.total = doc["total_usd"] | 0L;
  fresh.priced = doc["priced"] | 0;
  fresh.unslotted = doc["unslotted"].as<JsonArrayConst>().size();
  fresh.updated = doc["updated_label"] | "";
  for (size_t i = 0; i < 8; i++) {
    JsonObjectConst s = slots[i];
    if (!s["watch"].isNull()) {
      readWatch(s["watch"], s["slot"] | int(i + 1), fresh.slots[i]);
    } else {
      fresh.slots[i] = WatchInfo();
      fresh.slots[i].slot = i + 1;
    }
  }
  fresh.valid = true;
  out = fresh;
  return true;
}

bool fetchBox(const String& server, String& json) {
  HTTPClient http;
  if (!http.begin(server + "/api/box")) return false;
  http.useHTTP10(true);
  http.setConnectTimeout(3000);
  http.setTimeout(5000);
  int code = http.GET();
  if (code != HTTP_CODE_OK) {
    Serial.printf("GET /api/box failed: %d\n", code);
    http.end();
    return false;
  }
  json = http.getString();
  http.end();
  return json.length() > 0;
}

void saveCache(const String& json) {
  if (json.length() > MAX_CACHE) {
    Serial.println("cache: payload too large, not cached");
    return;
  }
  Preferences p;
  if (!p.begin(NS, false)) {
    Serial.println("cache: NVS open failed");
    return;
  }
  if (p.putBytes("box", json.c_str(), json.length()) != json.length()) Serial.println("cache: write failed");
  p.end();
}

bool loadCache(String& json) {
  Preferences p;
  if (!p.begin(NS, true)) return false;
  size_t n = p.getBytesLength("box");
  if (n == 0 || n > MAX_CACHE) {
    p.end();
    return false;
  }
  std::unique_ptr<char[]> buf(new char[n + 1]);
  p.getBytes("box", buf.get(), n);
  buf[n] = 0;
  p.end();
  json = String(buf.get());
  return true;
}
```

- [ ] **Step 3: `firmware/watchbox_35/screens.h`**

```cpp
#pragma once
#include <Arduino.h>

#include "data.h"

struct Area {
  int x, y, w, h;
  bool contains(int px, int py) const { return px >= x && px < x + w && py >= y && py < y + h; }
};

struct BoxStatus {
  bool wifi = false;
  String battery;       // "82%" or "USB"
  int batteryPct = -1;  // -1 on USB power
  String updated;       // "Oct 2, 1:14 PM" or ""
  bool offline = false;
  bool lowBattery = false;
};

namespace screens {
Area tileArea(int index);  // 0..7, slot = index + 1
Area menuArea();           // status-bar menu icon
Area backArea();           // status-bar "< Back"
Area resetButtonArea();    // settings: "Re-run setup"
Area confirmYesArea();
Area confirmNoArea();

void home(const BoxData& d, const BoxStatus& s);
void homeStatusBar(const BoxStatus& s);  // redraw only the status bar on the home screen
void detail(const BoxData& d, int index, const BoxStatus& s);
void settings(const BoxStatus& s, const String& server, int unslotted, const String& ssid, int rssi, int batteryMv);
void confirmReset();
void setup(const String& apName);
void waiting(const String& server, const BoxStatus& s);
}  // namespace screens
```

- [ ] **Step 4: `firmware/watchbox_35/screens.cpp`**

```cpp
#include "screens.h"

#include "board.h"
#include "format.h"
#include "theme.h"

using namespace theme;

namespace {
const char* FW_VERSION = "1.0.0";

uint16_t confidenceColor(const String& c) {
  if (c == "high") return CONF_HIGH;
  if (c == "medium") return CONF_MEDIUM;
  if (c == "low") return CONF_LOW;
  return NONE;
}

void text(const char* s, int x, int y, const lgfx::IFont* font, uint16_t color, uint8_t datum = top_left) {
  tft.setFont(font);
  tft.setTextColor(color);
  tft.setTextDatum(datum);
  tft.drawString(s, x, y);
}

void text(const String& s, int x, int y, const lgfx::IFont* font, uint16_t color, uint8_t datum = top_left) {
  text(s.c_str(), x, y, font, color, datum);
}

// Up to maxLines lines, breaking at spaces; the last line ends in "..." if the text doesn't fit.
void wrapText(const String& s, int x, int y, int maxW, int maxLines, const lgfx::IFont* font, uint16_t color) {
  tft.setFont(font);
  tft.setTextColor(color);
  tft.setTextDatum(top_left);
  int lineH = tft.fontHeight();
  String rest = s;
  for (int line = 0; line < maxLines && rest.length(); line++) {
    int fit = rest.length();
    while (fit > 1 && tft.textWidth(rest.substring(0, fit).c_str()) > maxW) fit--;
    if (fit < (int)rest.length() && line < maxLines - 1) {
      int space = rest.lastIndexOf(' ', fit);
      if (space > 0) fit = space;
    }
    String piece = rest.substring(0, fit);
    if (line == maxLines - 1 && fit < (int)rest.length()) {
      while (piece.length() && tft.textWidth((piece + "...").c_str()) > maxW) piece.remove(piece.length() - 1);
      piece += "...";
    }
    tft.drawString(piece.c_str(), x, y + line * lineH);
    rest = rest.substring(fit);
    rest.trim();
  }
}

// rightText replaces the Wi-Fi / battery / updated / menu indicators when given.
void statusBar(const char* left, const BoxStatus& s, const char* rightText = nullptr) {
  tft.fillRect(0, 0, W, BAR_H, BG);
  tft.drawFastHLine(0, BAR_H - 1, W, LINE);
  text(left, MARGIN, 5, &fonts::FreeSans9pt7b, MUTED);
  if (rightText) {
    text(rightText, W - MARGIN, 5, &fonts::FreeSans9pt7b, MUTED, top_right);
    return;
  }
  int x = W - MARGIN;
  for (int i = 0; i < 3; i++) tft.fillRect(x - 16, 7 + i * 5, 16, 2, MUTED);  // menu icon
  x -= 28;
  if (s.updated.length()) {
    text(s.updated, x, 5, &fonts::FreeSans9pt7b, MUTED, top_right);
    x -= tft.textWidth(s.updated.c_str()) + 12;
  }
  if (s.batteryPct >= 0) {  // battery outline with fill level
    tft.drawRect(x - 20, 7, 18, 10, MUTED);
    tft.fillRect(x - 2, 10, 2, 4, MUTED);
    int fill = (14 * s.batteryPct) / 100;
    tft.fillRect(x - 18, 9, fill, 6, s.lowBattery ? CONF_LOW : CONF_HIGH);
    x -= 26;
  }
  text(s.battery, x, 5, &fonts::FreeSans9pt7b, MUTED, top_right);
  x -= tft.textWidth(s.battery.c_str()) + 12;
  if (s.wifi) tft.fillCircle(x - 4, 12, 4, CONF_HIGH);
  else tft.drawCircle(x - 4, 12, 4, MUTED);
}

bool hasBanner(const BoxStatus& s) { return s.offline || s.lowBattery; }

void banner(const BoxStatus& s) {
  String msg;
  if (s.offline) msg = s.updated.length() ? "Can't reach the app - showing values from " + s.updated : "Can't reach the app";
  else if (s.lowBattery) msg = "Battery low - please charge";
  else return;
  tft.fillRect(0, BAR_H, W, 20, WARN_BG);
  text(msg, MARGIN, BAR_H + 3, &fonts::FreeSans9pt7b, GOLD);
}

void drawTile(const WatchInfo& w, const Area& r) {
  String num = String(w.slot);
  if (!w.present) {
    tft.fillRect(r.x, r.y, r.w, r.h, BG);
    tft.drawRoundRect(r.x, r.y, r.w, r.h, 8, LINE);
    text(num, r.x + 8, r.y + 6, &fonts::FreeSans9pt7b, NONE);
    text("Empty", r.x + 8, r.y + r.h / 2 - 8, &fonts::FreeSans9pt7b, NONE);
    return;
  }
  tft.fillRoundRect(r.x, r.y, r.w, r.h, 8, TILE);
  text(num, r.x + 8, r.y + 6, &fonts::FreeSans9pt7b, MUTED);
  tft.fillCircle(r.x + r.w - 12, r.y + 13, 4, confidenceColor(w.confidence));
  wrapText(w.name, r.x + 8, r.y + 30, r.w - 16, 2, &fonts::FreeSans9pt7b, TEXT);
  if (w.hasEstimate) {
    String price = String(w.estimatedRef ? "~" : "") + formatPrice(w.estimate);
    text(price, r.x + 8, r.y + r.h - 28, &fonts::FreeSansBold12pt7b, GOLD);
  } else {
    text("no price yet", r.x + 8, r.y + r.h - 24, &fonts::FreeSans9pt7b, MUTED);
  }
}

void column(int x, int y, const char* label, const String& value, const String& sub1, const String& sub2) {
  text(label, x, y, &fonts::FreeSans9pt7b, MUTED);
  text(value, x, y + 20, &fonts::FreeSansBold18pt7b, TEXT);
  text(sub1, x, y + 54, &fonts::FreeSans9pt7b, MUTED);
  if (sub2.length()) text(sub2, x, y + 72, &fonts::FreeSans9pt7b, MUTED);
}

void button(const Area& a, const char* label, uint16_t bg) {
  tft.fillRoundRect(a.x, a.y, a.w, a.h, 8, bg);
  text(label, a.x + a.w / 2, a.y + a.h / 2, &fonts::FreeSans9pt7b, TEXT, middle_center);
}
}  // namespace

Area screens::tileArea(int index) {
  int col = index % 4, row = index / 4;
  return {MARGIN + col * (TILE_W + GAP), GRID_TOP + row * (TILE_H + GAP), TILE_W, TILE_H};
}
Area screens::menuArea() { return {W - 56, 0, 56, BAR_H + 8}; }
Area screens::backArea() { return {0, 0, 110, BAR_H + 8}; }
Area screens::resetButtonArea() { return {190, 262, 170, 44}; }
Area screens::confirmNoArea() { return {90, 210, 130, 50}; }
Area screens::confirmYesArea() { return {260, 210, 130, 50}; }

void screens::homeStatusBar(const BoxStatus& s) { statusBar("WatchBox", s); }

void screens::home(const BoxData& d, const BoxStatus& s) {
  tft.fillScreen(BG);
  statusBar("WatchBox", s);
  banner(s);
  int ty = hasBanner(s) ? 48 : 32;
  text(formatPrice(d.total), MARGIN + 4, ty,
       hasBanner(s) ? &fonts::FreeSansBold18pt7b : &fonts::FreeSansBold24pt7b, GOLD);
  String caption = String(d.priced) + (d.priced == 1 ? " watch" : " watches") + " - market estimate";
  text(caption, W - MARGIN - 4, ty + 12, &fonts::FreeSans9pt7b, MUTED, top_right);
  for (int i = 0; i < 8; i++) drawTile(d.slots[i], tileArea(i));
}

void screens::detail(const BoxData& d, int index, const BoxStatus& s) {
  const WatchInfo& w = d.slots[index];
  tft.fillScreen(BG);
  String right = "Slot " + String(w.slot) + " of 8";
  statusBar("< Back", s, right.c_str());
  banner(s);
  int y = hasBanner(s) ? 50 : 32;
  text(w.brand + "  |  " + w.reference + "  |  " + w.details, MARGIN + 4, y, &fonts::FreeSans9pt7b, MUTED);
  text(w.name, MARGIN + 4, y + 20, &fonts::FreeSans18pt7b, TEXT);
  String est = w.hasEstimate ? String(w.estimatedRef ? "~" : "") + formatPrice(w.estimate) : String("no price yet");
  text(est, MARGIN + 4, y + 56, &fonts::FreeSansBold24pt7b, GOLD);
  int ex = MARGIN + 4 + tft.textWidth(est.c_str()) + 18;
  tft.fillCircle(ex, y + 76, 5, confidenceColor(w.confidence));
  text(w.confidence.length() ? w.confidence + " confidence" : String("no confidence data"), ex + 12, y + 68,
       &fonts::FreeSans9pt7b, TEXT);

  int cy = y + 116, cw = (W - 2 * MARGIN) / 3, cx = MARGIN + 4;
  if (w.hasEbay) {
    column(cx, cy, "EBAY SOLD 90 D", formatPrice(w.ebayMedian), String(w.ebayN) + " sales",
           formatK(w.ebayP10) + " - " + formatK(w.ebayP90));
  } else {
    column(cx, cy, "EBAY SOLD 90 D", "-", "not enough data", "");
  }
  if (w.hasC24) column(cx + cw, cy, "CHRONO24 ASKING", formatPrice(w.c24Median), String(w.c24N) + " listings", "");
  else column(cx + cw, cy, "CHRONO24 ASKING", "-", "not enough data", "");
  if (w.hasAcc) {
    char acc[16];
    snprintf(acc, sizeof acc, "+/-%.1f%%", w.mdape * 100);
    column(cx + 2 * cw, cy, "ACCURACY", acc, "backtest, " + String(w.accN) + " sales", "");
  } else {
    column(cx + 2 * cw, cy, "ACCURACY", "-", "not enough sales", "");
  }
  text("Updated " + w.asOf + "  |  eBay + Chrono24", MARGIN + 4, H - 22, &fonts::FreeSans9pt7b, MUTED);
}

void screens::settings(const BoxStatus& s, const String& server, int unslotted, const String& ssid, int rssi,
                       int batteryMv) {
  tft.fillScreen(BG);
  statusBar("< Back", s, "Settings");
  tft.fillRect(MARGIN, 40, 164, 164, WHITE);
  tft.qrcode(server.c_str(), MARGIN + 7, 47, 150);
  text("Open the app", MARGIN + 82, 212, &fonts::FreeSans9pt7b, TEXT, top_center);
  text("on your phone", MARGIN + 82, 230, &fonts::FreeSans9pt7b, TEXT, top_center);

  int x = 190, y = 40;
  auto line = [&](const char* label, const String& value) {
    text(label, x, y, &fonts::FreeSans9pt7b, MUTED);
    text(value, x, y + 18, &fonts::FreeSans9pt7b, TEXT);
    y += 44;
  };
  line("Wi-Fi", ssid.length() ? ssid + " (" + String(rssi) + " dBm)" : String("not connected"));
  line("App address", server);
  line("Battery", s.batteryPct >= 0 ? String(batteryMv / 1000.0, 2) + " V (" + s.battery + ")" : String("USB power"));
  line("Firmware", FW_VERSION);
  if (unslotted > 0) line("Not in a slot", String(unslotted) + (unslotted == 1 ? " watch" : " watches"));
  button(resetButtonArea(), "Re-run setup", BUTTON);
}

void screens::confirmReset() {
  tft.fillScreen(BG);
  text("Re-run setup?", W / 2, 70, &fonts::FreeSansBold18pt7b, TEXT, top_center);
  text("This clears the saved Wi-Fi. The box restarts", W / 2, 120, &fonts::FreeSans9pt7b, MUTED, top_center);
  text("and shows the setup QR code.", W / 2, 140, &fonts::FreeSans9pt7b, MUTED, top_center);
  button(confirmNoArea(), "Cancel", BUTTON);
  button(confirmYesArea(), "Yes, reset", CONF_LOW);
}

void screens::setup(const String& apName) {
  tft.fillScreen(BG);
  text("Set up your WatchBox", MARGIN + 4, 14, &fonts::FreeSansBold18pt7b, TEXT);
  String wifiQr = "WIFI:T:nopass;S:" + apName + ";;";
  tft.fillRect(MARGIN, 60, 174, 174, WHITE);
  tft.qrcode(wifiQr.c_str(), MARGIN + 7, 67, 160);
  int x = 200, y = 70;
  const String lines[] = {"1. Scan to join " + apName, "2. The setup page opens.", "   If not, go to 192.168.4.1",
                          "3. Choose your Wi-Fi, enter the", "   app address, and save."};
  for (const String& l : lines) {
    text(l, x, y, &fonts::FreeSans9pt7b, TEXT);
    y += 26;
  }
  text("Waiting for setup...", x, y + 20, &fonts::FreeSans9pt7b, MUTED);
}

void screens::waiting(const String& server, const BoxStatus& s) {
  tft.fillScreen(BG);
  statusBar("WatchBox", s);
  text("Waiting for the app at", W / 2, 120, &fonts::FreeSans12pt7b, TEXT, top_center);
  text(server, W / 2, 152, &fonts::FreeSans12pt7b, GOLD, top_center);
  text("Check that the Mac app is running on the same Wi-Fi.", W / 2, 200, &fonts::FreeSans9pt7b, MUTED,
       top_center);
}
```

- [ ] **Step 5: `firmware/watchbox_35/input.h` and `input.cpp`**

```cpp
#pragma once

enum class Gesture { None, Tap, SwipeLeft, SwipeRight };

struct TouchEvent {
  Gesture gesture = Gesture::None;
  int x = 0, y = 0;
};

namespace input {
void ignoreIfTouching();  // after waking from sleep: the waking touch is not a tap
TouchEvent poll();        // call every loop; reports a gesture when the finger lifts
}  // namespace input
```

```cpp
#include "input.h"

#include <stdlib.h>

#include "board.h"

namespace {
const int SWIPE_MIN = 60;    // px of horizontal travel for a swipe
const int RELEASE_POLLS = 3; // resistive touch flickers; require a few empty reads before "lifted"
bool down = false, ignoring = false;
int startX = 0, startY = 0, lastX = 0, lastY = 0, emptyPolls = 0;
}  // namespace

void input::ignoreIfTouching() {
  int32_t x, y;
  if (tft.getTouch(&x, &y)) {
    down = true;
    ignoring = true;
    startX = lastX = x;
    startY = lastY = y;
  }
}

TouchEvent input::poll() {
  TouchEvent ev;
  int32_t x, y;
  if (tft.getTouch(&x, &y)) {
    if (!down) {
      down = true;
      startX = x;
      startY = y;
    }
    lastX = x;
    lastY = y;
    emptyPolls = 0;
    return ev;
  }
  if (!down || ++emptyPolls < RELEASE_POLLS) return ev;
  down = false;
  emptyPolls = 0;
  if (ignoring) {
    ignoring = false;
    return ev;
  }
  int dx = lastX - startX, dy = lastY - startY;
  if (abs(dx) >= SWIPE_MIN && abs(dx) > abs(dy)) ev.gesture = dx < 0 ? Gesture::SwipeLeft : Gesture::SwipeRight;
  else ev.gesture = Gesture::Tap;
  ev.x = startX;
  ev.y = startY;
  return ev;
}
```

- [ ] **Step 6: `firmware/watchbox_35/power.h` and `power.cpp`**

```cpp
#pragma once
#include <Arduino.h>

namespace power {
enum class Action { None, Dim, Sleep };
int batteryMv();         // via the board's 1:2 divider on IO34 (verify with a multimeter)
bool onUsb(int mv);      // implausible reading = no battery fitted -> USB power
int batteryPct(int mv);  // -1 on USB
bool wokeFromTouch();
void noteActivity();     // any touch: resets the idle timer and undims
Action update(bool usb); // call every loop
void sleepNow();         // deep sleep until the screen is touched; does not return
}  // namespace power
```

```cpp
#include "power.h"

#include <WiFi.h>
#include <esp_sleep.h>

#include "board.h"

namespace {
const unsigned long DIM_AFTER_BATTERY = 120000;  // 2 min
const unsigned long DIM_AFTER_USB = 600000;      // 10 min
const unsigned long SLEEP_AFTER_DIM = 15000;
const uint8_t BRIGHT = 200, DIMMED = 30;
const int BATTERY_PIN = 34;
unsigned long lastActivity = 0;
bool dimmed = false;
}  // namespace

int power::batteryMv() { return analogReadMilliVolts(BATTERY_PIN) * 2; }

bool power::onUsb(int mv) { return mv < 2500 || mv > 4500; }

int power::batteryPct(int mv) {
  if (onUsb(mv)) return -1;
  long pct = map(mv, 3300, 4150, 0, 100);
  return constrain(pct, 0L, 100L);
}

bool power::wokeFromTouch() { return esp_sleep_get_wakeup_cause() == ESP_SLEEP_WAKEUP_EXT0; }

void power::noteActivity() {
  lastActivity = millis();
  if (dimmed) {
    dimmed = false;
    tft.setBrightness(BRIGHT);
  }
}

power::Action power::update(bool usb) {
  unsigned long idle = millis() - lastActivity;
  unsigned long dimAfter = usb ? DIM_AFTER_USB : DIM_AFTER_BATTERY;
  if (!dimmed && idle >= dimAfter) {
    dimmed = true;
    tft.setBrightness(DIMMED);
    return Action::Dim;
  }
  if (dimmed && idle >= dimAfter + SLEEP_AFTER_DIM) return Action::Sleep;
  return Action::None;
}

void power::sleepNow() {
  tft.setBrightness(0);
  tft.sleep();
  WiFi.disconnect(true);
  WiFi.mode(WIFI_OFF);
  esp_sleep_enable_ext0_wakeup(GPIO_NUM_36, 0);  // XPT2046 pen interrupt goes low on touch
  esp_deep_sleep_start();
}
```

- [ ] **Step 7: `firmware/watchbox_35/net.h` and `net.cpp`**

```cpp
#pragma once
#include <Arduino.h>

namespace net {
String apName();                                     // "WatchBox-XXXX"
String server();                                     // saved app address, "" if none
bool configured();                                   // Wi-Fi and app address saved
void runSetup(void (*onPortal)(const String& ap));  // blocking hotspot setup; restarts when done
void begin();                                        // connect with saved credentials (non-blocking)
bool connected();
void maintain();                                     // reconnect attempt every 30 s while offline
void resetAndRestart();                              // forget Wi-Fi + app address, restart into setup
}  // namespace net
```

```cpp
#include "net.h"

#include <Preferences.h>
#include <WiFi.h>
#include <WiFiManager.h>

namespace {
const char* NS = "watchbox";
const char* DEFAULT_SERVER = "http://watchbox.local:8000";
unsigned long lastAttempt = 0;
void (*portalCallback)(const String&) = nullptr;

void saveServer(const String& s) {
  Preferences p;
  p.begin(NS, false);
  p.putString("server", s);
  p.end();
}
}  // namespace

String net::apName() {
  char buf[20];
  snprintf(buf, sizeof buf, "WatchBox-%04X", (unsigned)((ESP.getEfuseMac() >> 32) & 0xFFFF));
  return String(buf);
}

String net::server() {
  Preferences p;
  p.begin(NS, true);
  String s = p.getString("server", "");
  p.end();
  return s;
}

bool net::configured() {
  WiFiManager wm;
  return wm.getWiFiIsSaved() && server().length() > 0;
}

void net::runSetup(void (*onPortal)(const String& ap)) {
  portalCallback = onPortal;
  String current = server();
  if (!current.length()) current = DEFAULT_SERVER;
  WiFiManager wm;
  WiFiManagerParameter serverField("server", "App address (e.g. http://192.168.1.50:8000)", current.c_str(), 80);
  wm.addParameter(&serverField);
  wm.setTitle("WatchBox setup");
  wm.setConfigPortalTimeout(600);
  wm.setAPCallback([](WiFiManager*) {
    if (portalCallback) portalCallback(net::apName());
  });
  String ap = apName();
  if (onPortal) onPortal(ap);
  if (wm.startConfigPortal(ap.c_str())) {
    String s = serverField.getValue();
    s.trim();
    while (s.endsWith("/")) s.remove(s.length() - 1);
    saveServer(s);
  }
  ESP.restart();
}

void net::begin() {
  WiFi.mode(WIFI_STA);
  WiFi.setAutoReconnect(true);
  WiFi.begin();  // credentials saved by WiFiManager
  lastAttempt = millis();
}

bool net::connected() { return WiFi.status() == WL_CONNECTED; }

void net::maintain() {
  if (!connected() && millis() - lastAttempt > 30000) {
    lastAttempt = millis();
    WiFi.reconnect();
  }
}

void net::resetAndRestart() {
  WiFiManager wm;
  wm.resetSettings();
  Preferences p;
  p.begin(NS, false);
  p.remove("server");
  p.remove("box");
  p.end();
  ESP.restart();
}
```

- [ ] **Step 8: Replace `firmware/watchbox_35/watchbox_35.ino`**

```cpp
// WatchBox 3.5" firmware: slot map, watch detail, settings and hotspot setup on the ESP32-32E board.
// Data comes from the Mac app's GET /api/box; the last good payload is cached so wake-up is instant.
#include <WiFi.h>

#include "board.h"
#include "data.h"
#include "input.h"
#include "net.h"
#include "power.h"
#include "screens.h"
#include "theme.h"

LGFX tft;

enum class Screen { Home, Detail, Settings, ConfirmReset };

namespace {
const unsigned long FETCH_INTERVAL = 60000;
const unsigned long DETAIL_TIMEOUT = 30000;
const unsigned long STATUS_INTERVAL = 30000;
const unsigned long OFFLINE_AFTER = 20000;  // no Wi-Fi this long after boot -> offline banner

BoxData box;
BoxStatus status;
Screen screen = Screen::Home;
int detailIndex = 0;
String serverUrl, lastJson;
unsigned long lastFetch = 0, lastStatus = 0, screenSince = 0;
bool fetchedThisBoot = false, needRedraw = true;
}  // namespace

void refreshStatus() {
  int mv = power::batteryMv();
  status.batteryPct = power::batteryPct(mv);
  status.battery = status.batteryPct < 0 ? String("USB") : String(status.batteryPct) + "%";
  status.lowBattery = status.batteryPct >= 0 && status.batteryPct < 10;
  status.wifi = net::connected();
  status.updated = box.valid ? box.updated : String("");
}

void draw() {
  refreshStatus();
  switch (screen) {
    case Screen::Home:
      if (box.valid) screens::home(box, status);
      else screens::waiting(serverUrl, status);
      break;
    case Screen::Detail:
      screens::detail(box, detailIndex, status);
      break;
    case Screen::Settings:
      screens::settings(status, serverUrl, box.unslotted, WiFi.SSID(), WiFi.RSSI(), power::batteryMv());
      break;
    case Screen::ConfirmReset:
      screens::confirmReset();
      break;
  }
  needRedraw = false;
}

void show(Screen s) {
  screen = s;
  screenSince = millis();
  needRedraw = true;
}

int nextWatch(int from, int step) {
  for (int i = 1; i <= 8; i++) {
    int j = (from + step * i + 16) % 8;
    if (box.slots[j].present) return j;
  }
  return from;
}

void handleTouch(const TouchEvent& ev) {
  if (ev.gesture == Gesture::None) return;
  power::noteActivity();
  bool tap = ev.gesture == Gesture::Tap;
  switch (screen) {
    case Screen::Home:
      if (tap && screens::menuArea().contains(ev.x, ev.y)) {
        show(Screen::Settings);
        return;
      }
      if (tap && box.valid) {
        for (int i = 0; i < 8; i++) {
          if (box.slots[i].present && screens::tileArea(i).contains(ev.x, ev.y)) {
            detailIndex = i;
            show(Screen::Detail);
            return;
          }
        }
      }
      break;
    case Screen::Detail:
      if (ev.gesture == Gesture::SwipeLeft) {
        detailIndex = nextWatch(detailIndex, 1);
        show(Screen::Detail);
      } else if (ev.gesture == Gesture::SwipeRight) {
        detailIndex = nextWatch(detailIndex, -1);
        show(Screen::Detail);
      } else if (screens::backArea().contains(ev.x, ev.y)) {
        show(Screen::Home);
      }
      break;
    case Screen::Settings:
      if (!tap) break;
      if (screens::backArea().contains(ev.x, ev.y)) show(Screen::Home);
      else if (screens::resetButtonArea().contains(ev.x, ev.y)) show(Screen::ConfirmReset);
      break;
    case Screen::ConfirmReset:
      if (!tap) break;
      if (screens::confirmYesArea().contains(ev.x, ev.y)) {
        screens::setup(net::apName());
        net::resetAndRestart();
      } else if (screens::confirmNoArea().contains(ev.x, ev.y)) {
        show(Screen::Settings);
      }
      break;
  }
}

void tryFetch() {
  if (!net::connected()) return;
  if (fetchedThisBoot && millis() - lastFetch < FETCH_INTERVAL) return;
  lastFetch = millis();
  fetchedThisBoot = true;
  String json;
  BoxData fresh;
  if (fetchBox(serverUrl, json) && parseBox(json, fresh)) {
    bool changed = json != lastJson || status.offline;
    box = fresh;
    status.offline = false;
    if (json != lastJson) saveCache(json);
    lastJson = json;
    if (changed) needRedraw = true;
  } else if (!status.offline) {
    status.offline = true;
    needRedraw = true;
  }
}

void setup() {
  Serial.begin(115200);
  tft.init();
  tft.setRotation(1);
  tft.setTouchCalibrate(TOUCH_CAL);
  tft.setBrightness(200);
  if (power::wokeFromTouch()) input::ignoreIfTouching();

  serverUrl = net::server();
  if (!net::configured()) net::runSetup(screens::setup);  // does not return

  String cached;
  if (loadCache(cached) && parseBox(cached, box)) lastJson = cached;
  draw();  // instant: cached values (or "waiting for the app")
  net::begin();
  power::noteActivity();
}

void loop() {
  handleTouch(input::poll());
  net::maintain();
  tryFetch();

  if (!net::connected() && millis() > OFFLINE_AFTER && !status.offline) {
    status.offline = true;
    needRedraw = true;
  }
  if (screen == Screen::Detail && millis() - screenSince > DETAIL_TIMEOUT) show(Screen::Home);
  if (millis() - lastStatus > STATUS_INTERVAL) {
    lastStatus = millis();
    if (screen == Screen::Home && box.valid && !needRedraw) {
      refreshStatus();
      screens::homeStatusBar(status);
    }
  }
  if (power::update(status.batteryPct < 0) == power::Action::Sleep) power::sleepNow();
  if (needRedraw) draw();
  delay(10);
}
```

- [ ] **Step 9: Compile**

Run: `~/.local/bin/arduino-cli compile --fqbn esp32:esp32:esp32:PartitionScheme=huge_app firmware/watchbox_35 2>&1 | grep -E "error|warning: .*watchbox_35|Sketch uses"`
Expected: a `Sketch uses …` line with no errors, and no warnings from files in `firmware/watchbox_35/`.

If a LovyanGFX or WiFiManager API call doesn't compile, check the installed library's header (under `~/Documents/Arduino/libraries/`) and use the equivalent call with the same behaviour. Then update the code block in this plan to match.

- [ ] **Step 10: Commit**

```bash
git add firmware/watchbox_35
git commit -m "feat: 3.5\" firmware: slot map, detail, settings, hotspot setup, sleep"
```

---

### Task 4: Spec alignment

**Files:** Modify `docs/superpowers/specs/2026-10-02-display-35-design.md`

- [ ] **Step 1:** Add a section "Implementation notes (2026-10-02)" at the end, listing the refinements from this plan's header:
  - `updated_label` and `as_of_label` fields;
  - ASCII-folded strings and short `details` labels;
  - the ASCII stand-ins (menu icon, "< Back", "+/-", "-");
  - 9 pt tile names;
  - waking from sleep always shows home.

  Also replace `·` with `,` in the `details` example of section 1.

- [ ] **Step 2: Commit**

```bash
git add docs/superpowers/specs/2026-10-02-display-35-design.md
git commit -m "docs: display spec implementation notes"
```

---

### Task 5: [CONTROLLER] Flash and hands-on acceptance

- [ ] **Step 1:** Restart the Mac app on the latest code so `/api/box` exists. Check that `curl -s localhost:8000/api/box | python3 -m json.tool | head -30` shows 8 slots.
- [ ] **Step 2:** Flash:

```bash
~/.local/bin/arduino-cli compile --upload -p /dev/cu.usbserial-110 --fqbn esp32:esp32:esp32:PartitionScheme=huge_app,UploadSpeed=460800 firmware/watchbox_35
```

- [ ] **Step 3:** Run the spec's acceptance checklist (§7) with the owner, one step at a time:
  1. Setup through the hotspot. App address: `http://192.168.1.176:8000`.
  2. Home shows the 4 watches and empty slots 5–8.
  3. Tapping a tile opens its detail.
  4. Swiping moves between watches.
  5. The screen returns home after 30 s.
  6. The Settings QR code opens the app.
  7. With the Mac app stopped, the offline banner shows over cached values.
  8. After 2 minutes on battery (10 on USB) the screen dims, then sleeps; a touch wakes it instantly.
  9. Re-run setup works.
- [ ] **Step 4:** Fix anything found (systematic-debugging), and record results in the spec.

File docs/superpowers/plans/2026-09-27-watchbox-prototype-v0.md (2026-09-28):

# WatchBox Prototype v0 Implementation Plan

> **For agentic workers:** REQUIRED SUB-SKILL: Use superpowers:subagent-driven-development (recommended) or superpowers:executing-plans to implement this plan task-by-task. Steps use checkbox (`- [ ]`) syntax for tracking.

**Goal:** A local web app on the Mac stores watches and fetches eBay prices. The kit ESP32 pulls ready-to-show lines from it and cycles them on a 16×2 I2C LCD. Both parts live in a 3D-printed enclosure.

**Architecture:** A Python FastAPI app with SQLite owns all logic. It holds watches and price history, fetches prices through a swappable `PriceProvider` (eBay Browse API), and formats 16-character LCD lines. The ESP32 firmware is a thin client that fetches `GET /api/display` every 60 s and shows each screen for 4 s. The enclosure is a parametric OpenSCAD file exported to two STLs for Bambu Studio.

**Tech Stack:** Python 3.13, FastAPI, Jinja2, httpx, SQLite (stdlib), pytest · Arduino C++ via arduino-cli (esp32 core, LiquidCrystal_I2C, ArduinoJson 7) · OpenSCAD.

**Spec:** `docs/superpowers/specs/2026-09-27-watchbox-prototype-v0-design.md`

**Conventions:**
- Run every command from the repo root unless a step says otherwise.
- Steps marked **[USER]** need the physical hardware or the user's accounts. An agent stops at them and asks the user.

---

## File map

```
server/
  requirements.txt          # Python deps
  pytest.ini                # pytest config (pythonpath=.)
  .env.example              # EBAY_CLIENT_ID, EBAY_CLIENT_SECRET, REFRESH_HOURS, PORT, DB_PATH
  watchbox/
    __init__.py
    __main__.py             # `python -m watchbox`: builds provider, prints LAN URL, runs uvicorn
    config.py               # Settings dataclass + load_settings() from .env
    pricing.py              # PriceResult, PriceProvider protocol, junk/ref filtering, median
    db.py                   # SQLite schema, Watch dataclass, CRUD, price history
    display.py              # format_price, fit (16 chars), time_ago, build_screens
    ebay.py                 # EbayBrowseProvider (OAuth token cache + search)
    refresh.py              # refresh_watch / refresh_all / needs_refresh
    app.py                  # create_app(): HTML pages, form handlers, /api/display, scheduler
    templates/
      base.html             # layout + CSS
      index.html            # list, total, add form, refresh button
      edit.html             # edit + delete
      _form.html            # shared watch form
  scripts/
    check_price.py          # manual eBay sanity check for one reference
  tests/
    fixtures/ebay_search_126610ln.json
    test_pricing.py
    test_db.py
    test_display.py
    test_ebay.py
    test_refresh.py
    test_app.py
firmware/
  i2c_scan/i2c_scan.ino     # prints LCD I2C address
  watchbox_v0/
    watchbox_v0.ino         # main firmware
    config.example.h        # committed template
    config.h                # gitignored, user's Wi-Fi + server URL
enclosure/
  watchbox_v0.scad          # parametric enclosure (part = front | back | assembly)
README.md                   # how to run everything
```

---

### Task 1: Server scaffolding

**Files:**
- Create: `server/requirements.txt`, `server/pytest.ini`, `server/watchbox/__init__.py`, `server/tests/__init__.py`

- [ ] **Step 1: Create `server/requirements.txt`**

```text
fastapi>=0.115
uvicorn>=0.30
jinja2>=3.1
python-multipart>=0.0.9
httpx>=0.27
python-dotenv>=1.0
pytest>=8.0
```

- [ ] **Step 2: Create `server/pytest.ini`**

```ini
[pytest]
pythonpath = .
testpaths = tests
```

- [ ] **Step 3: Create empty package files**

`server/watchbox/__init__.py` and `server/tests/__init__.py` are both empty files.

- [ ] **Step 4: Create the virtualenv and install**

Run:
```bash
python3 -m venv server/.venv && server/.venv/bin/pip install -q -r server/requirements.txt
```
Expected: exits 0.

- [ ] **Step 5: Verify pytest runs**

Run: `server/.venv/bin/pytest server/tests -q`
Expected: `no tests ran` (exit code 5 is fine here).

- [ ] **Step 6: Commit**

```bash
git add server/requirements.txt server/pytest.ini server/watchbox/__init__.py server/tests/__init__.py
git commit -m "chore: scaffold WatchBox server"
```

---

### Task 2: Pricing core (filtering + median)

**Files:**
- Create: `server/watchbox/pricing.py`
- Test: `server/tests/test_pricing.py`

- [ ] **Step 1: Write the failing tests**

`server/tests/test_pricing.py`:
```python
from watchbox.pricing import PriceResult, filter_listings, is_junk, listing_matches, summarize_prices

def test_is_junk_flags_accessory_listings():
    assert is_junk("Rolex Submariner 126610LN BOX ONLY")
    assert is_junk("Homage Submariner 126610LN style automatic")
    assert is_junk("Rolex 126610LN bezel insert black")

def test_is_junk_keeps_normal_titles():
    assert not is_junk("Rolex Submariner Date 126610LN Black Ceramic Bezel 2023")
    assert not is_junk("Rolex 126610LN Oyster bracelet full set")

def test_listing_matches_reference_ignoring_spacing_and_case():
    assert listing_matches("Rolex Submariner 126610 LN 2022", "126610LN")
    assert listing_matches("omega speedmaster 310.30.42.50.01.001", "310304250 01001")
    assert not listing_matches("Rolex Submariner 124060", "126610LN")

def test_filter_listings_keeps_matching_non_junk_prices():
    listings = [
        ("Rolex Submariner 126610 LN 2022", 13000.0),
        ("Rolex Submariner 124060", 9500.0),
        ("Rolex 126610LN box only", 900.0),
    ]
    assert filter_listings(listings, "126610LN") == [13000.0]

def test_summarize_returns_median_after_outlier_removal():
    prices = [12000.0, 13000.0, 13500.0, 14000.0, 60000.0, 1000.0]
    listings = [(f"Rolex 126610LN #{i}", p) for i, p in enumerate(prices)]
    # median of all six = 13250 -> keep [6625, 26500] -> 12000, 13000, 13500, 14000 -> median 13250
    assert summarize_prices(listings, "126610LN", "ebay") == PriceResult(price_usd=13250.0, sample_size=4, source="ebay")

def test_summarize_needs_at_least_three_listings():
    listings = [("Rolex 126610LN", 13000.0), ("Rolex 126610LN", 13500.0)]
    assert summarize_prices(listings, "126610LN", "ebay") is None

def test_summarize_returns_none_when_outlier_removal_leaves_too_few():
    # 3 listings pass the reference/junk filter, but the 0.5x-2x band around
    # the median of [100, 100, 100000] (100) only keeps the two 100s.
    listings = [("Rolex 126610LN #1", 100.0), ("Rolex 126610LN #2", 100.0), ("Rolex 126610LN #3", 100000.0)]
    assert summarize_prices(listings, "126610LN", "ebay") is None

def test_listing_matches_returns_false_for_empty_reference():
    assert listing_matches("Rolex Submariner", "") is False
    assert listing_matches("Rolex Submariner", "-") is False

def test_is_junk_manual_and_repair_refinements():
    assert not is_junk("Omega Speedmaster Professional Manual Wind 310.30.42.50.01.001")
    assert is_junk("Rolex instruction manual 126610LN")
    assert is_junk("Rolex 126610LN needs repair")
```

- [ ] **Step 2: Run to verify failure**

Run: `server/.venv/bin/pytest server/tests/test_pricing.py -q`
Expected: FAIL, `ModuleNotFoundError: No module named 'watchbox.pricing'`

- [ ] **Step 3: Implement `server/watchbox/pricing.py`**

```python
"""Price provider interface and the provider-independent price math."""
import re
from dataclasses import dataclass
from statistics import median
from typing import Protocol

MIN_SAMPLES = 3

JUNK_PHRASES = (
    "box only", "papers only", "empty box", "strap only", "bracelet only", "band only",
    "links only", "dial only", "bezel only", "bezel insert", "crown only", "case back",
    "for parts", "parts only", "for repair", "needs repair", "repair only", "homage", "replica",
    "instruction manual", "manual only", "booklet",
)

@dataclass(frozen=True)
class PriceResult:
    price_usd: float
    sample_size: int
    source: str

class PriceProvider(Protocol):
    def get_price(self, brand: str, reference: str) -> PriceResult | None: ...

def _norm(text: str) -> str:
    return re.sub(r"[^a-z0-9]", "", text.lower())

def is_junk(title: str) -> bool:
    lowered = title.lower()
    return any(phrase in lowered for phrase in JUNK_PHRASES)

def listing_matches(title: str, reference: str) -> bool:
    norm_reference = _norm(reference)
    if not norm_reference:
        return False
    return norm_reference in _norm(title) and not is_junk(title)

def filter_listings(listings: list[tuple[str, float]], reference: str) -> list[float]:
    return [price for title, price in listings if listing_matches(title, reference)]

def summarize_prices(listings: list[tuple[str, float]], reference: str, source: str) -> PriceResult | None:
    prices = filter_listings(listings, reference)
    if len(prices) < MIN_SAMPLES:
        return None
    mid = median(prices)
    kept = [p for p in prices if 0.5 * mid <= p <= 2 * mid]
    if len(kept) < MIN_SAMPLES:
        return None
    return PriceResult(price_usd=round(median(kept), 2), sample_size=len(kept), source=source)
```

- [ ] **Step 4: Run to verify pass**

Run: `server/.venv/bin/pytest server/tests/test_pricing.py -q`
Expected: `9 passed`

- [ ] **Step 5: Commit**

```bash
git add server/watchbox/pricing.py server/tests/test_pricing.py
git commit -m "feat: price filtering and median summary"
```

---

### Task 3: SQLite storage

**Files:**
- Create: `server/watchbox/db.py`
- Test: `server/tests/test_db.py`

- [ ] **Step 1: Write the failing tests**

`server/tests/test_db.py`:
```python
import pytest

from watchbox import db
from watchbox.pricing import PriceResult

@pytest.fixture
def conn(tmp_path):
    c = db.connect(tmp_path / "t.db")
    yield c
    c.close()

def test_add_and_list_uses_latest_price(conn):
    wid = db.add_watch(conn, "Rolex", "Submariner", "126610LN", 1, None)
    db.add_price(conn, wid, PriceResult(13000.0, 20, "ebay"), fetched_at="2026-09-27T10:00:00+00:00")
    db.add_price(conn, wid, PriceResult(13400.0, 22, "ebay"), fetched_at="2026-09-27T16:00:00+00:00")
    [w] = db.list_watches(conn)
    assert (w.id, w.model, w.slot, w.price_usd, w.sample_size) == (wid, "Submariner", 1, 13400.0, 22)
    assert db.latest_fetch_time(conn) == "2026-09-27T16:00:00+00:00"

def test_list_orders_by_slot_with_unslotted_last(conn):
    db.add_watch(conn, "Cartier", "Tank Must", "WSTA0041", None, None)
    db.add_watch(conn, "Omega", "Speedmaster", "310.30.42.50.01.001", 2, None)
    db.add_watch(conn, "Rolex", "Submariner", "126610LN", 1, None)
    assert [w.model for w in db.list_watches(conn)] == ["Submariner", "Speedmaster", "Tank Must"]

def test_slot_must_be_unique(conn):
    db.add_watch(conn, "Rolex", "Submariner", "126610LN", 1, None)
    with pytest.raises(db.SlotTakenError, match="Slot 1 is already taken"):
        db.add_watch(conn, "Omega", "Speedmaster", "310.30.42.50.01.001", 1, None)

def test_update_keeps_prices_when_reference_unchanged(conn):
    wid = db.add_watch(conn, "Rolex", "Submariner", "126610LN", 1, None)
    db.add_price(conn, wid, PriceResult(13000.0, 20, "ebay"))
    db.update_watch(conn, wid, "Rolex", "Submariner Date", "126610LN", 2, "Sub")
    w = db.get_watch(conn, wid)
    assert (w.model, w.slot, w.nickname, w.price_usd) == ("Submariner Date", 2, "Sub", 13000.0)

def test_update_clears_prices_when_reference_changes(conn):
    wid = db.add_watch(conn, "Rolex", "Submariner", "126610LN", 1, None)
    db.add_price(conn, wid, PriceResult(13000.0, 20, "ebay"))
    db.update_watch(conn, wid, "Rolex", "GMT-Master II", "126710BLRO", 1, None)
    assert db.get_watch(conn, wid).price_usd is None

def test_update_clears_prices_when_only_brand_changes(conn):
    wid = db.add_watch(conn, "Rolex", "Submariner", "126610LN", 1, None)
    db.add_price(conn, wid, PriceResult(13000.0, 20, "ebay"))
    db.update_watch(conn, wid, "Tudor", "Submariner", "126610LN", 1, None)
    assert db.get_watch(conn, wid).price_usd is None

def test_delete_removes_watch_and_prices(conn):
    wid = db.add_watch(conn, "Rolex", "Submariner", "126610LN", 1, None)
    db.add_price(conn, wid, PriceResult(13000.0, 20, "ebay"))
    db.delete_watch(conn, wid)
    assert db.list_watches(conn) == []
    assert conn.execute("SELECT COUNT(*) FROM prices").fetchone()[0] == 0

def test_get_missing_watch_returns_none(conn):
    assert db.get_watch(conn, 999) is None
```

- [ ] **Step 2: Run to verify failure**

Run: `server/.venv/bin/pytest server/tests/test_db.py -q`
Expected: FAIL, `ImportError: cannot import name 'db'`

- [ ] **Step 3: Implement `server/watchbox/db.py`**

```python
"""SQLite storage for watches and their price history."""
import sqlite3
from dataclasses import dataclass
from datetime import datetime, timezone
from os import PathLike

from .pricing import PriceResult

SCHEMA = """
CREATE TABLE IF NOT EXISTS watches (
    id INTEGER PRIMARY KEY AUTOINCREMENT,
    brand TEXT NOT NULL,
    model TEXT NOT NULL,
    reference TEXT NOT NULL,
    slot INTEGER UNIQUE CHECK (slot BETWEEN 1 AND 8),
    nickname TEXT,
    created_at TEXT NOT NULL
);
CREATE TABLE IF NOT EXISTS prices (
    id INTEGER PRIMARY KEY AUTOINCREMENT,
    watch_id INTEGER NOT NULL REFERENCES watches(id) ON DELETE CASCADE,
    price_usd REAL NOT NULL,
    sample_size INTEGER NOT NULL,
    source TEXT NOT NULL,
    fetched_at TEXT NOT NULL
);
"""

_SELECT = """
SELECT w.id, w.brand, w.model, w.reference, w.slot, w.nickname,
       p.price_usd, p.sample_size, p.fetched_at
FROM watches w
LEFT JOIN prices p ON p.id = (
    SELECT id FROM prices WHERE watch_id = w.id ORDER BY fetched_at DESC, id DESC LIMIT 1
)
"""

@dataclass
class Watch:
    id: int
    brand: str
    model: str
    reference: str
    slot: int | None
    nickname: str | None
    price_usd: float | None = None
    sample_size: int | None = None
    fetched_at: str | None = None

class SlotTakenError(Exception):
    def __init__(self, slot: int | None):
        super().__init__(f"Slot {slot} is already taken")
        self.slot = slot

def now_iso() -> str:
    return datetime.now(timezone.utc).isoformat(timespec="seconds")

def connect(path: str | PathLike) -> sqlite3.Connection:
    # FastAPI may run a dependency and its endpoint on different threads; each
    # connection is still used by one request at a time.
    conn = sqlite3.connect(path, check_same_thread=False)
    conn.row_factory = sqlite3.Row
    conn.execute("PRAGMA foreign_keys = ON")
    conn.executescript(SCHEMA)
    return conn

def _write(conn: sqlite3.Connection, sql: str, params: tuple, slot: int | None, commit: bool = True) -> sqlite3.Cursor:
    try:
        cur = conn.execute(sql, params)
    except sqlite3.IntegrityError as e:
        if "UNIQUE" in str(e):
            raise SlotTakenError(slot) from e
        raise
    if commit:
        conn.commit()
    return cur

def list_watches(conn: sqlite3.Connection) -> list[Watch]:
    rows = conn.execute(_SELECT + " ORDER BY w.slot IS NULL, w.slot, w.id").fetchall()
    return [Watch(**dict(r)) for r in rows]

def get_watch(conn: sqlite3.Connection, watch_id: int) -> Watch | None:
    row = conn.execute(_SELECT + " WHERE w.id = ?", (watch_id,)).fetchone()
    return Watch(**dict(row)) if row else None

def add_watch(conn, brand: str, model: str, reference: str, slot: int | None, nickname: str | None) -> int:
    cur = _write(
        conn,
        "INSERT INTO watches (brand, model, reference, slot, nickname, created_at) VALUES (?, ?, ?, ?, ?, ?)",
        (brand, model, reference, slot, nickname, now_iso()),
        slot,
    )
    return cur.lastrowid

def update_watch(conn, watch_id: int, brand: str, model: str, reference: str, slot: int | None, nickname: str | None) -> None:
    old = conn.execute("SELECT brand, reference FROM watches WHERE id = ?", (watch_id,)).fetchone()
    _write(
        conn,
        "UPDATE watches SET brand = ?, model = ?, reference = ?, slot = ?, nickname = ? WHERE id = ?",
        (brand, model, reference, slot, nickname, watch_id),
        slot,
        commit=False,
    )
    if old and (old["brand"], old["reference"]) != (brand, reference):
        conn.execute("DELETE FROM prices WHERE watch_id = ?", (watch_id,))
    conn.commit()

def delete_watch(conn: sqlite3.Connection, watch_id: int) -> None:
    conn.execute("DELETE FROM watches WHERE id = ?", (watch_id,))
    conn.commit()

def add_price(conn: sqlite3.Connection, watch_id: int, result: PriceResult, fetched_at: str | None = None) -> None:
    conn.execute(
        "INSERT INTO prices (watch_id, price_usd, sample_size, source, fetched_at) VALUES (?, ?, ?, ?, ?)",
        (watch_id, result.price_usd, result.sample_size, result.source, fetched_at or now_iso()),
    )
    conn.commit()

def latest_fetch_time(conn: sqlite3.Connection) -> str | None:
    return conn.execute("SELECT MAX(fetched_at) FROM prices").fetchone()[0]
```

- [ ] **Step 4: Run to verify pass**

Run: `server/.venv/bin/pytest server/tests/test_db.py -q`
Expected: `8 passed`

- [ ] **Step 5: Commit**

```bash
git add server/watchbox/db.py server/tests/test_db.py
git commit -m "feat: SQLite storage for watches and price history"
```

---

### Task 4: LCD display formatting

**Files:**
- Create: `server/watchbox/display.py`
- Test: `server/tests/test_display.py`

- [ ] **Step 1: Write the failing tests**

`server/tests/test_display.py`:
```python
from datetime import datetime, timezone

from watchbox.db import Watch
from watchbox.display import build_screens, fit, format_price, time_ago

def w(id, model, slot=None, price=None, nickname=None):
    return Watch(id=id, brand="Rolex", model=model, reference="X", slot=slot, nickname=nickname, price_usd=price)

def test_format_price_whole_dollars_with_commas():
    assert format_price(13400.4) == "$13,400"
    assert format_price(999_999) == "$999,999"

def test_format_price_switches_to_millions_when_too_long():
    assert format_price(1_234_567) == "$1.2M"
    assert format_price(999_999.6) == "$1.0M"

def test_fit_truncates_to_16_ascii_chars():
    assert fit("1 Royal Oak Offshore Chronograph") == "1 Royal Oak Offs"
    assert fit("Café Racer") == "Caf Racer"

def test_fit_leaves_exactly_16_chars_unchanged():
    text = "1234567890123456"
    assert len(text) == 16
    assert fit(text) == text

def test_empty_collection():
    assert build_screens([]) == [{"line1": "No watches yet", "line2": "Add on the app"}]

def test_total_first_then_slots_in_order_unslotted_last():
    watches = [
        w(1, "Tank Must", slot=None, price=2600),
        w(2, "Speedmaster", slot=2, price=6150),
        w(3, "Submariner", slot=1, price=13400),
        w(4, "Nautilus", slot=3),
    ]
    assert build_screens(watches) == [
        {"line1": "TOTAL 3 watches", "line2": "$22,150"},
        {"line1": "1 Submariner", "line2": "$13,400"},
        {"line1": "2 Speedmaster", "line2": "$6,150"},
        {"line1": "3 Nautilus", "line2": "no price yet"},
        {"line1": "Tank Must", "line2": "$2,600"},
    ]

def test_nickname_wins_and_total_is_singular():
    assert build_screens([w(1, "Submariner", slot=5, price=100, nickname="Dad's Sub")]) == [
        {"line1": "TOTAL 1 watch", "line2": "$100"},
        {"line1": "5 Dad's Sub", "line2": "$100"},
    ]

def test_time_ago():
    now = datetime(2026, 9, 27, 12, 0, tzinfo=timezone.utc)
    assert time_ago(None, now) == "never"
    assert time_ago("2026-09-27T11:59:30+00:00", now) == "just now"
    assert time_ago("2026-09-27T11:15:00+00:00", now) == "45 min ago"
    assert time_ago("2026-09-27T06:00:00+00:00", now) == "6 h ago"
    assert time_ago("2026-09-24T12:00:00+00:00", now) == "3 d ago"

def test_time_ago_treats_naive_timestamp_as_utc():
    now = datetime(2026, 9, 27, 12, 0, tzinfo=timezone.utc)
    assert time_ago("2026-09-27T11:15:00", now) == "45 min ago"
```

- [ ] **Step 2: Run to verify failure**

Run: `server/.venv/bin/pytest server/tests/test_display.py -q`
Expected: FAIL, `ModuleNotFoundError: No module named 'watchbox.display'`

- [ ] **Step 3: Implement `server/watchbox/display.py`**

```python
"""Turns watches into short, ready-to-show lines for the 16x2 LCD."""
from datetime import datetime, timezone

from .db import Watch

LCD_WIDTH = 16

def fit(text: str) -> str:
    """ASCII only (the LCD can't draw accents), cut to one LCD line."""
    return text.encode("ascii", "ignore").decode()[:LCD_WIDTH]

def format_price(value: float) -> str:
    text = f"${value:,.0f}"
    if len(text) > 9:
        text = f"${value / 1_000_000:.1f}M"
    return text

def time_ago(iso: str | None, now: datetime | None = None) -> str:
    if not iso:
        return "never"
    now = now or datetime.now(timezone.utc)
    then = datetime.fromisoformat(iso)
    if then.tzinfo is None:
        then = then.replace(tzinfo=timezone.utc)
    seconds = (now - then).total_seconds()
    if seconds < 60:
        return "just now"
    if seconds < 3600:
        return f"{int(seconds // 60)} min ago"
    if seconds < 86400:
        return f"{int(seconds // 3600)} h ago"
    return f"{int(seconds // 86400)} d ago"

def display_name(watch: Watch) -> str:
    name = watch.nickname or watch.model
    return f"{watch.slot} {name}" if watch.slot is not None else name

def build_screens(watches: list[Watch]) -> list[dict[str, str]]:
    if not watches:
        return [{"line1": "No watches yet", "line2": "Add on the app"}]
    ordered = sorted(watches, key=lambda w: (w.slot is None, w.slot or 0, w.id))
    priced = [w for w in ordered if w.price_usd is not None]
    noun = "watch" if len(priced) == 1 else "watches"
    screens = [{
        "line1": fit(f"TOTAL {len(priced)} {noun}"),
        "line2": fit(format_price(sum(w.price_usd for w in priced))),
    }]
    for watch in ordered:
        price = format_price(watch.price_usd) if watch.price_usd is not None else "no price yet"
        screens.append({"line1": fit(display_name(watch)), "line2": fit(price)})
    return screens
```

- [ ] **Step 4: Run to verify pass**

Run: `server/.venv/bin/pytest server/tests/test_display.py -q`
Expected: `9 passed`

- [ ] **Step 5: Commit**

```bash
git add server/watchbox/display.py server/tests/test_display.py
git commit -m "feat: LCD screen formatting"
```

---
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

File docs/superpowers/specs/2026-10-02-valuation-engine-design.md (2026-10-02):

# WatchBox v1, Part 1: Valuation Engine: Design

**Date:** 2026-10-02
**Status:** Approved in brainstorming, awaiting spec review
**Builds on:** `2026-09-27-watchbox-prototype-v0-design.md`, which is implemented in `server/`.

## Context

WatchBox v1 is three sub-projects, built in this order:

1. **Valuation engine** (this spec). It produces the most accurate estimate it can for each watch from several sources, adjusted for the watch's details.
2. **Web app, accounts and QR setup.** Each owner has a collection list with per-watch details. On first setup the box shows a QR code that opens the app's setup page and pairs the box to the account. This gets its own spec.
3. **3.5" display firmware.** The target board is an **ESP32-32E 3.5" LCD, 320×480, resistive touch**: panel HSD035577A3 (ST7796 driver), with a `BAT` LiPo connector, microSD and USB-C. It measures about 56 × 99 mm and 10.6 mm deep, and the long side still needs confirming. The screens show the slot map, plus per-watch detail: eBay 90-day sold median and range, Chrono24 asking price, and the estimate. This gets its own spec.

The v0 server already supports `PriceProvider` sources (eBay Browse, TheWatchAPI). TheWatchAPI's data ends in 2024-07, and eBay developer keys couldn't be obtained. Testing on 2026-10-02 showed that two Apify tools by `memo23` return good current data:
- **eBay sold listings, last 90 days:** for 116610LN, 30 sales with a median of about $11,500.
- **Chrono24 asking prices:** for 116610LN, 20 listings with a median of about $12,250.

The owner has decided to optimize for accuracy, not for data cost.

## Goals

1. Estimate each watch's resale value from comparable sales and listings, adjusted for its condition, box & papers, year, dial, bracelet and case metal.
2. Expose the underlying figures: eBay 90-day sold count, median and range, and Chrono24 asking count and median.
3. Report a confidence level backed by a measured accuracy check (the backtest).
4. Recalculate instantly when an owner edits a watch's details, without fetching new data.

## Non-goals (this part)

- Accounts, pairing and QR setup (part 2).
- 3.5" screens (part 3). The 16×2 LCD keeps showing one estimate per watch.
- The WatchCharts integration. The design leaves room for it as a third source, added once a key exists.
- Sold-price sources other than eBay.

## 1. Watch details (data model)

The `watches` table gains these columns. Older databases get them added on connect, like `price_date` and `price_reference` before them.

| Column | Type | Values | Default |
|---|---|---|---|
| `reference` | TEXT NOT NULL (existing) | may now be `""` when the owner doesn't know it | `""` |
| `year` | INTEGER NULL | 1900–current year | NULL |
| `condition` | TEXT | `new`, `excellent`, `very_good`, `good`, `fair` | `excellent` |
| `box_papers` | TEXT | `full_set`, `box_only`, `papers_only`, `watch_only` | `full_set` |
| `dial` | TEXT NULL | `black`, `blue`, `white`, `silver`, `green`, `grey`, `champagne`, `brown`, `red`, `other` | NULL |
| `bracelet` | TEXT NULL | `oyster`, `jubilee`, `president`, `leather`, `rubber`, `nato`, `other` | NULL |
| `metal` | TEXT NULL | `steel`, `yellow_gold`, `white_gold`, `rose_gold`, `two_tone`, `platinum`, `titanium`, `other` | NULL |

- **Validation:** brand and model are required. A reference, if given, must contain letters or digits.
- **Reference rule:** when `reference` is empty, the engine searches by brand and model plus whichever of dial and metal are set.
- **Web form:** the add and edit forms gain these fields, as dropdowns for the fixed lists.
- **Unchanged:** `price_reference`, the "price using reference" option, still overrides which reference is searched.

## 2. Sources and comparables

### Comparable (one normalized listing)

```
Comparable:
  source: "ebay" | "chrono24"
  kind: "sold" | "asking"
  price_usd: float
  date: date            # sold date for eBay, scraped date for Chrono24
  title: str
  url: str
  reference: str | None
  year: int | None
  condition: str | None   # same vocabulary as watches.condition
  box_papers: str | None
  dial: str | None
  bracelet: str | None
  metal: str | None
  best_offer: bool        # eBay "best offer accepted": the shown price may be above the real sale price
```

### Source interface

`ComparableSource.fetch(query: WatchQuery) -> list[Comparable]`, where `WatchQuery` holds brand, model, reference and the optional details. Network errors raise `SourceError`.

### `ApifyEbaySoldSource`
- **Actor:** `memo23/ebay-search-scraper-ppe`, called through `run-sync-get-dataset-items`.
- **Input:** `mode=sold`, `soldWithinDays=90`, `category=31387`, `marketplace=ebay.com`, `detailedItems=false`, `includeSummary=false`, `maxItems=60`, `searchQuery="<brand> <reference>"`. When there's no reference, the query is `"<brand> <model> <dial>"`.
- **Rows:** keep rows with a `priceValue` in USD.
  - `soldDate` (format `"Sold  Aug 31, 2026"`) is parsed to a date.
  - `bestOfferAccepted` is mapped to `best_offer`.

### `ApifyChrono24Source`
- **Actor:** `memo23/chrono24-scraper`.
- **Input:**
  - `startUrls=[https://www.chrono24.com/search/index.htm?query=<brand>+<reference>&dosearch=true]`
  - `fetchListingDetails=true`, so the listing's spec table is included: condition, scope of delivery, year, dial, bracelet, case material.
  - `maxIndexPages=1`, `maxItems=40`.
- **Rows:** keep rows priced in USD. The search URL sets `currencyId=USD`, and rows in other currencies are dropped.
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

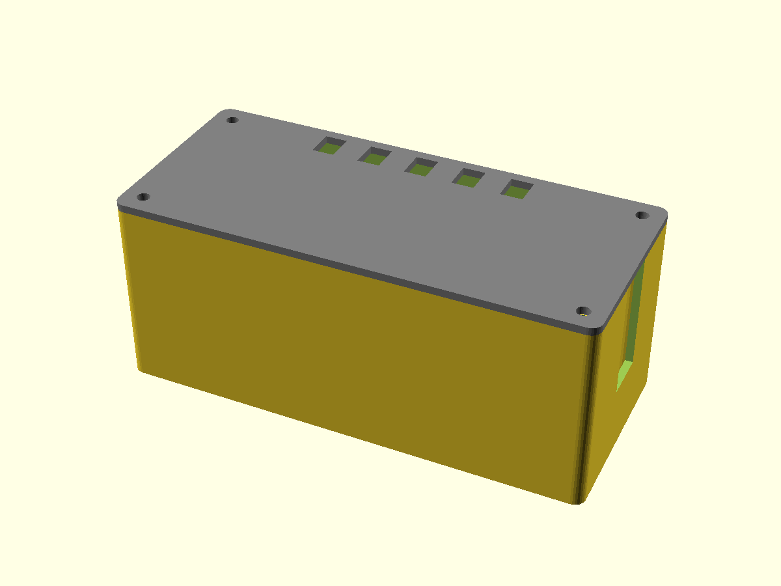
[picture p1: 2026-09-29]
enclosure/preview.png

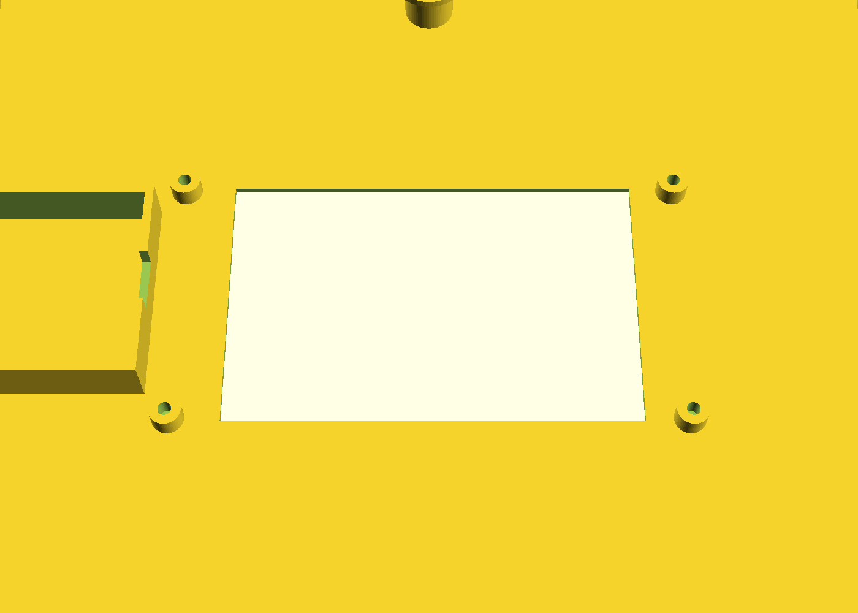
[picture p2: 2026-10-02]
enclosure/lid_liner_back.png

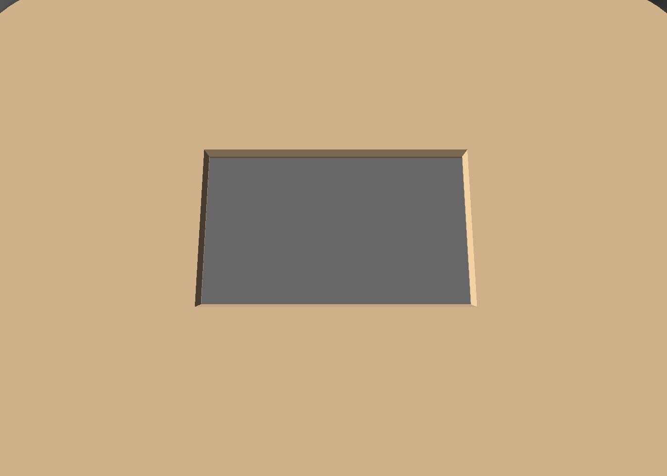
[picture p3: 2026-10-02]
enclosure/lid_liner_in_lid.png

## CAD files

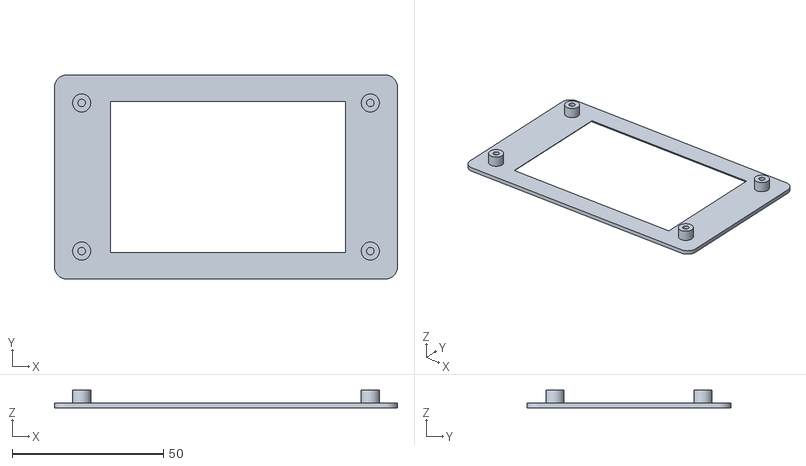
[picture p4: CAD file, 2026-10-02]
enclosure/lid_liner_coupon.stl
113.5 x 67.5 x 5.80

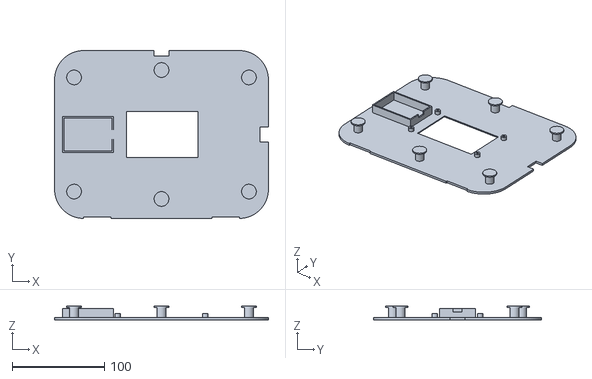
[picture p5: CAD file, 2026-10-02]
enclosure/lid_liner.stl
232.5 x 182.5 x 14.8

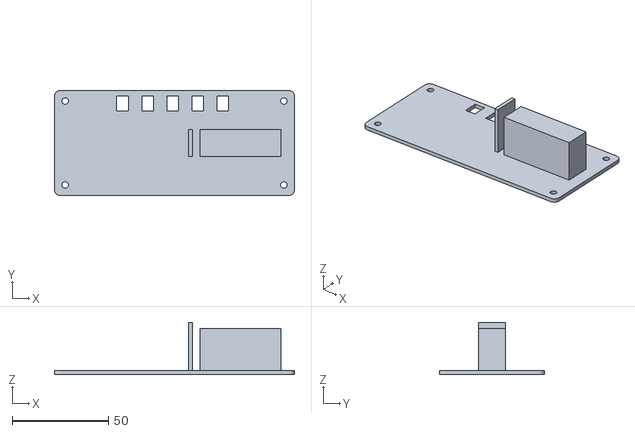
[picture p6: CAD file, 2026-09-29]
enclosure/watchbox_v0_back.stl
124.6 x 54.6 x 27.0

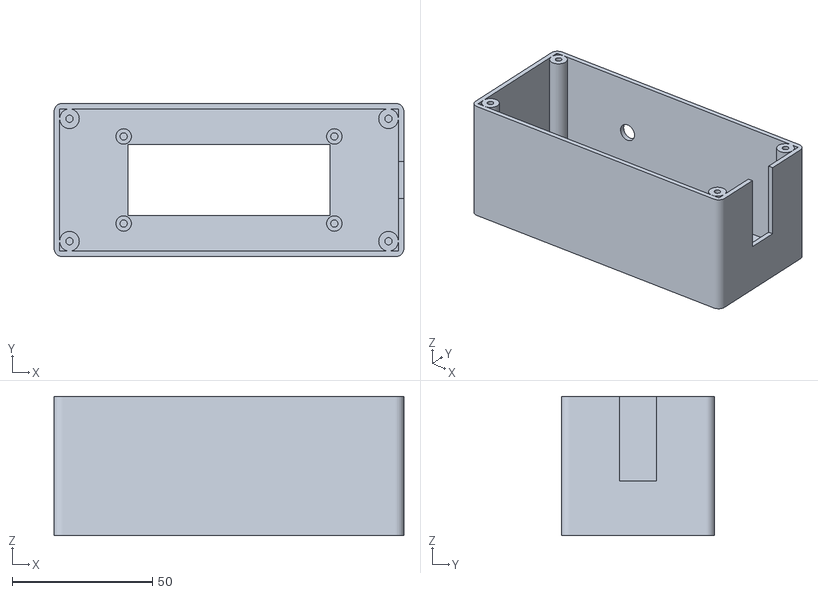
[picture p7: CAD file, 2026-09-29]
enclosure/watchbox_v0_front.stl
124.6 x 54.6 x 49.6

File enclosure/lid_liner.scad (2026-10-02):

// WatchBox lid liner: a plate that fills the inside of the heavy-duty case lid (obj_3_top.stl),
// holding the ESP32-32E 3.5" display board behind a framed window, with a battery bay and cable notches.
//
// Export:  openscad -D 'part="liner"'  -o lid_liner.stl      lid_liner.scad
//          openscad -D 'part="coupon"' -o lid_liner_coupon.stl lid_liner.scad   (quick fit test, ~15 min)
//          part="assembly" shows the liner inside the lid (needs the lid STL path below).
// Print the liner and coupon FRONT FACE DOWN (as exported), no supports. Units: mm.

part = "liner";
lid_stl = "/Users/gabrielfarkas/Downloads/heavydutycase_stls (1)/obj_3_top.stl";

// ---------- Lid interior (measured from obj_3_top.stl) ----------
lid_floor_z   = 2.9;    // inside face of the lid's top plate
open_w        = 233.5;  // lid opening at liner_back_z (walls curve out from 217.5 at the floor to 234 at z=17)
open_h        = 183.5;
open_r        = 32.4;   // corner radius of the opening at that height
liner_back_z  = 15.4;   // height of the liner's back face -> 12.5 mm of space behind it for the board
fit_clearance = 0.5;    // per side; press-fit gap to the lid wall (tape on the legs holds it)

// ---------- Liner plate ----------
plate_t       = 2.5;
window_bevel  = 1.5;    // 45° chamfer around the window on the front face

// ---------- ESP32-32E 3.5" board (LCDwiki/Elecrow E32R35T: 101.5 x 55.5, touch area 77.24 x 49.5) ----------
board         = [101.5, 55.5];
hole_sp       = [95.5, 49.0];  // ESTIMATED from photo: measure centre-to-centre of the 4 corner holes!
glass_stack   = 4.2;           // PCB front face to touch-glass front face (module 5.8 total - 1.6 PCB)
glass_offset  = [0.7, 0];      // touch-glass centre relative to board centre (ESTIMATED; check with coupon)
window        = [77.24 + 0.6, 49.5 + 0.6];  // touch visual area + margin, so the full touch area works
board_pos     = [0, 0];        // board centre on the liner (liner centre = lid centre)
post_d        = 6;
screw_pilot   = 2.5;           // M3 self-tapping (2.2 for M2.5)

// ---------- Battery bay (flat LiPo, e.g. 103450 / 2000 mAh = 50 x 34 x 10) ----------
batt          = [52, 36];      // inner pocket
batt_pos      = [-80, 0];       // keeps the bay clear of the lid's curved lower wall
batt_wall     = 1.6;
batt_h        = 10;

// ---------- Legs (rest on the lid floor, foam tape on the feet) ----------
leg_d         = 10;
leg_foot_d    = 16;
leg_pos       = [[-95, 62], [95, 62], [-95, -62], [95, -62], [0, 70], [0, -70]];

// ---------- Cable notches in the plate edge ----------
usb_notch     = [16, 9];   // right edge, by the board's USB-C side: route a short right-angle USB-C cable
hinge_notch   = [16, 6];   // top edge: future slot-sensor wiring from the base
latch_relief  = [30, 1.5]; // bottom edge: clears two inward bosses on the lid wall at x = ±70
latch_x       = [-70, 70];

// ---------- Derived ----------
$fn = 64;
plate_w = open_w - 2 * fit_clearance;
plate_h = open_h - 2 * fit_clearance;
plate_r = open_r - fit_clearance;
leg_h   = liner_back_z - lid_floor_z - 0.2;   // 0.2 for tape squish
glass_c = board_pos + glass_offset;

module rounded_rect(w, h, r, t) {
  hull() for (x = [-w / 2 + r, w / 2 - r], y = [-h / 2 + r, h / 2 - r]) translate([x, y, 0]) cylinder(r = r, h = t);
}

module window_cut(t) {
  // straight cut, plus a 45° chamfer opening toward the front face (z = 0, the print bed side)
  translate([glass_c.x - window.x / 2, glass_c.y - window.y / 2, -1]) cube([window.x, window.y, t + 2]);
  hull() {
    translate([glass_c.x - window.x / 2 - window_bevel, glass_c.y - window.y / 2 - window_bevel, -0.01])
      cube([window.x + 2 * window_bevel, window.y + 2 * window_bevel, 0.01]);
    translate([glass_c.x - window.x / 2, glass_c.y - window.y / 2, window_bevel]) cube([window.x, window.y, 0.01]);
  }
}

module board_posts(t) {
  for (sx = [-1, 1], sy = [-1, 1]) translate([board_pos.x + sx * hole_sp.x / 2, board_pos.y + sy * hole_sp.y / 2, t])
    difference() {
      cylinder(d = post_d, h = glass_stack);
      translate([0, 0, 0.6]) cylinder(d = screw_pilot, h = glass_stack);   // blind from the plate side
    }
}

module battery_bay(t) {
  translate([batt_pos.x, batt_pos.y, t]) difference() {
    translate([-batt.x / 2 - batt_wall, -batt.y / 2 - batt_wall, 0]) cube([batt.x + 2 * batt_wall, batt.y + 2 * batt_wall, batt_h]);
    translate([-batt.x / 2, -batt.y / 2, -1]) cube([batt.x, batt.y, batt_h + 2]);
    translate([batt.x / 2 - 1, -5, batt_h - 4]) cube([batt_wall + 2, 10, 5]);   // lead exit toward the board
  }
}

module legs(t) {
  for (p = leg_pos) translate([p.x, p.y, t]) {
    cylinder(d = leg_d, h = leg_h - 1.5);
    translate([0, 0, leg_h - 1.5]) cylinder(d = leg_foot_d, h = 1.5);   // pad for foam tape
  }
}

module liner() {
  difference() {
    union() {
      rounded_rect(plate_w, plate_h, plate_r, plate_t);
      board_posts(plate_t);
      battery_bay(plate_t);
      legs(plate_t);
    }
    window_cut(plate_t);
    // USB-C cable notch, right edge (x+), and wiring notch, top edge (y+)
    translate([plate_w / 2 - usb_notch.y, board_pos.y - usb_notch.x / 2, -1]) cube([usb_notch.y + 1, usb_notch.x, plate_t + 2]);
    translate([-hinge_notch.x / 2, plate_h / 2 - hinge_notch.y, -1]) cube([hinge_notch.x, hinge_notch.y + 1, plate_t + 2]);
    for (x = latch_x) translate([x - latch_relief.x / 2, -plate_h / 2 - 1, -1]) cube([latch_relief.x, latch_relief.y + 1, plate_t + 2]);
  }
}

module coupon() {
  // just the window region, thin, with the 4 posts: checks hole spacing and glass alignment fast
  ct = 1.6;
  difference() {
    union() {
      translate([board_pos.x, board_pos.y, 0]) rounded_rect(board.x + 12, board.y + 12, 4, ct);
      board_posts(ct);
    }
    window_cut(ct);
  }
}

if (part == "liner") {
  liner();
} else if (part == "coupon") {
  coupon();
} else if (part == "fitcheck") {
  // anything left here = the liner collides with the lid (should render empty)
  intersection() {
    translate([-310.2 - 125, -38 - 100, 0]) import(lid_stl);
    translate([0, 0, liner_back_z + plate_t]) mirror([0, 0, 1]) liner();
  }
} else {
  color("dimgray") translate([-310.2 - 125, -38 - 100, 0]) import(lid_stl);
  color("tan") translate([0, 0, liner_back_z + plate_t]) mirror([0, 0, 1]) liner();
}

echo(str("Liner ", plate_w, " x ", plate_h, " x ", plate_t, " mm plate; legs ", leg_h, " mm; front face ",
         34.8 - liner_back_z - plate_t, " mm below the lid rim"));

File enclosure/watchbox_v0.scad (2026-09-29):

// WatchBox v0 enclosure: I2C LCD1602 on the front, ESP32 devkit on a rail on the back plate.
// Export:  openscad -D 'part="front"' -o front.stl watchbox_v0.scad   (part = "front" | "back" | "assembly")
// Units: mm. Front shell prints face-down; back plate prints flat, rail up. No supports.

part = "assembly";

// ---------- Measure your parts and edit these ----------
lcd_pcb        = [80, 36];         // LCD PCB width x height
lcd_hole_sp    = [75, 31];         // LCD mounting-hole spacing (centre to centre)
lcd_frame      = [71, 24.44, 7];   // display frame w x h (measured), and how far it stands off the PCB front
lcd_back_depth = 9.4;              // PCB back to top of the I2C backpack (18 mm measured total - 7 frame - 1.6 PCB)
lcd_side_room  = 20;               // room beyond each short edge of the LCD PCB (backpack connectors stick out sideways)
esp_board      = [50, 27];         // ESP32 board length x width (measured NodeMCU-32S)
esp_raise      = 22;               // rail height: room for header plastic + Dupont housings + wire bend
esp_top        = 4;                // tallest part on top of the ESP32 (module / USB socket)
usb_cut        = [13, 9];          // cable plug clearance (width x height)
screw_pilot    = 2.6;              // pilot hole for M3 self-tapping (2.2 for M2.5)
screw_clear    = 3.4;              // clearance hole in the back plate
wall           = 2;
clr            = 0.3;
window_clr     = 0.5;              // extra room around the display frame
gap            = 4;                // air gap between LCD stack and ESP32 stack
button_hole    = true;             // hole in the top wall for the optional GPIO4 button
button_d       = 7;
// --------------------------------------------------------

$fn = 32;
boss_d = 7;
in_w = lcd_pcb.x + 2 * clr + 2 * lcd_side_room;
in_h = lcd_pcb.y + 2 * clr + 14;
lcd_post_h = lcd_frame.z - wall;                         // frame face ends flush with the front
lcd_stack = lcd_post_h + 1.6 + lcd_back_depth;
esp_stack = esp_raise + 1.6 + esp_top;
in_d = lcd_stack + gap + esp_stack;
out = [in_w + 2 * wall, in_h + 2 * wall, in_d + wall];  // front shell, open at the back
cx = out.x / 2;
cy = out.y / 2;

// ESP32 footprint (shared by shell USB notch and back-plate rail): USB end near the right wall.
esp_x1 = wall + in_w - 1;
esp_x0 = esp_x1 - esp_board.x;
usb_z = out.z - esp_raise - 1.6 - esp_top / 2;          // USB socket centre, measured from front face

boss_pos = [for (x = [wall + boss_d / 2, out.x - wall - boss_d / 2],
                 y = [wall + boss_d / 2, out.y - wall - boss_d / 2]) [x, y]];
lcd_holes = [for (sx = [-1, 1], sy = [-1, 1]) [cx + sx * lcd_hole_sp.x / 2, cy + sy * lcd_hole_sp.y / 2]];

module rounded_box(size, r = 3) {
  hull() for (x = [r, size.x - r], y = [r, size.y - r]) translate([x, y, 0]) cylinder(r = r, h = size.z);
}

module front_shell() {
  difference() {
    union() {
      difference() {
        rounded_box(out);
        translate([wall, wall, wall]) cube([in_w, in_h, in_d + 1]);
      }
      for (p = lcd_holes) translate([p.x, p.y, wall]) cylinder(d = 5.5, h = lcd_post_h);
      for (p = boss_pos) translate([p.x, p.y, wall]) cylinder(d = boss_d, h = in_d);
    }
    // display window (the LCD frame sits in it, flush with the face)
    translate([cx - lcd_frame.x / 2 - window_clr, cy - lcd_frame.y / 2 - window_clr, -1])
      cube([lcd_frame.x + 2 * window_clr, lcd_frame.y + 2 * window_clr, wall + 2]);
    // LCD post pilot holes (blind: they don't pierce the front face)
    for (p = lcd_holes) translate([p.x, p.y, wall + 0.6]) cylinder(d = screw_pilot, h = lcd_post_h);
    // back-plate screw pilots
    for (p = boss_pos) translate([p.x, p.y, out.z - 12]) cylinder(d = screw_pilot, h = 13);
    // USB notch in the right wall, open to the back edge
    translate([out.x - wall - 1, cy - usb_cut.x / 2, usb_z - usb_cut.y / 2])
      cube([wall + 2, usb_cut.x, out.z]);
    // optional button hole in the top wall, behind the LCD stack
    if (button_hole)
      translate([cx - 25, out.y - wall - 1, wall + lcd_stack + 8])
        rotate([-90, 0, 0]) cylinder(d = button_d, h = wall + 2);
  }
}

module back_plate() {
  difference() {
    union() {
      rounded_box([out.x, out.y, wall]);
      // ESP32 rail between the pin rows; stick the board on with foam tape
      translate([esp_x0 + 4, cy - 7, wall]) cube([esp_board.x - 8, 14, esp_raise]);
      // stop at the antenna end so the board can't slide left (the right wall stops it the other way)
      translate([esp_x0 - 2, cy - 7, wall]) cube([2, 14, esp_raise + 3]);
    }
    for (p = boss_pos) translate([p.x, p.y, -1]) cylinder(d = screw_clear, h = wall + 2);
    // vent slots beside the board
    for (i = [0 : 4]) translate([cx - 30 + i * 13, cy + esp_board.y / 2 + 3, -1]) cube([6, 8, wall + 2]);
  }
}

if (part == "front") {
  front_shell();
} else if (part == "back") {
  back_plate();
} else {
  front_shell();
  color("gray") translate([0, 0, out.z + wall]) mirror([0, 0, 1]) back_plate();
}

echo(str("Outer size: ", out.x, " x ", out.y, " x ", out.z + wall, " mm"));

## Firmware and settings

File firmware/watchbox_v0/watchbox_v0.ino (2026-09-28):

// WatchBox v0: shows the collection value from the Mac app on a 16x2 I2C LCD.
// The server does all formatting; this sketch fetches /api/display and cycles screens.
#include <WiFi.h>
#include <HTTPClient.h>
#include <ArduinoJson.h>
#include <Wire.h>
#include <LiquidCrystal_I2C.h>
#include "config.h"

const unsigned long FETCH_INTERVAL_MS = 60000;
const unsigned long SCREEN_INTERVAL_MS = 4000;
const unsigned long DEBOUNCE_MS = 300;
const unsigned long WIFI_CONNECT_TIMEOUT_MS = 60000;
const unsigned long WIFI_RECONNECT_INTERVAL_MS = 30000;
const unsigned long WIFI_RESTART_TIMEOUT_MS = 300000;
const int BUTTON_PIN = 4;  // optional push button to GND: next screen + refetch
const int MAX_SCREENS = 16;

struct Screen {
  char line1[17];
  char line2[17];
};

LiquidCrystal_I2C lcd(LCD_ADDR, 16, 2);
Screen screens[MAX_SCREENS];
int screenCount = 0;
int nextScreen = 0;
unsigned long screensShown = 0;
bool lastFetchOk = false;
bool haveFetched = false;
unsigned long lastFetchAt = 0;
unsigned long lastScreenAt = 0;
unsigned long lastButtonAt = 0;
int lastButtonLevel = HIGH;
unsigned long disconnectedAt = 0;
unsigned long lastReconnectAttempt = 0;

// Pads to 16 chars instead of lcd.clear() so the screen doesn't flicker.
void show(const char* line1, const char* line2) {
  char buf[17];
  snprintf(buf, sizeof(buf), "%-16s", line1);
  lcd.setCursor(0, 0);
  lcd.print(buf);
  snprintf(buf, sizeof(buf), "%-16s", line2);
  lcd.setCursor(0, 1);
  lcd.print(buf);
}

bool fetchDisplay() {
  HTTPClient http;
  if (!http.begin(String(SERVER_URL) + "/api/display")) return false;
  http.useHTTP10(true);
  http.setConnectTimeout(2000);
  http.setTimeout(3000);
  int code = http.GET();
  if (code != HTTP_CODE_OK) {
    Serial.printf("GET /api/display failed: %d\n", code);
    http.end();
    return false;
  }
  JsonDocument doc;
  DeserializationError err = deserializeJson(doc, http.getStream());
  http.end();
  if (err) {
    Serial.printf("JSON error: %s\n", err.c_str());
    return false;
  }
  if (!doc["screens"].is<JsonArray>()) {
    Serial.println("JSON error: \"screens\" is not an array");
    return false;
  }
  int count = 0;
  for (JsonObject s : doc["screens"].as<JsonArray>()) {
    if (count >= MAX_SCREENS) break;
    strlcpy(screens[count].line1, s["line1"] | "", sizeof(screens[count].line1));
    strlcpy(screens[count].line2, s["line2"] | "", sizeof(screens[count].line2));
    count++;
  }
  screenCount = count;
  if (nextScreen >= screenCount) nextScreen = 0;
  Serial.printf("Fetched %d screens\n", screenCount);
  return true;
}

void showNextScreen() {
  screensShown++;
  // Offline: keep showing the last good data, but every 3rd screen says so.
  if (!lastFetchOk && (screenCount == 0 || screensShown % 3 == 0)) {
    show("Server offline", "retrying...");
    return;
  }
  if (screenCount == 0) {
    show("No data", "");
    return;
  }
  show(screens[nextScreen].line1, screens[nextScreen].line2);
  nextScreen = (nextScreen + 1) % screenCount;
}

void setup() {
  Serial.begin(115200);
  pinMode(BUTTON_PIN, INPUT_PULLUP);
  lcd.init();
  lcd.backlight();
  show("WatchBox v0", "WiFi...");
  WiFi.mode(WIFI_STA);
  WiFi.setAutoReconnect(true);
  WiFi.begin(WIFI_SSID, WIFI_PASS);
  unsigned long connectStart = millis();
  while (WiFi.status() != WL_CONNECTED) {
    if (millis() - connectStart >= WIFI_CONNECT_TIMEOUT_MS) {
      Serial.printf("WiFi connect timed out, status=%d, restarting\n", WiFi.status());
      ESP.restart();
    }
    Serial.printf("WiFi status: %d\n", WiFi.status());
    delay(250);
  }
  Serial.print("WiFi connected, IP ");
  Serial.println(WiFi.localIP());
  show("WatchBox v0", "Loading...");
}

void loop() {
  unsigned long now = millis();
  int buttonLevel = digitalRead(BUTTON_PIN);
  bool pressed = buttonLevel == LOW && lastButtonLevel == HIGH && now - lastButtonAt > DEBOUNCE_MS;
  if (pressed) lastButtonAt = now;
  lastButtonLevel = buttonLevel;

  if (WiFi.status() != WL_CONNECTED) {
    if (disconnectedAt == 0) {
      disconnectedAt = now;
      lastReconnectAttempt = now;
    }
    show("WatchBox v0", "WiFi...");
    if (now - disconnectedAt >= WIFI_RESTART_TIMEOUT_MS) {
      Serial.println("WiFi disconnected too long, restarting");
      ESP.restart();
    }
    if (now - lastReconnectAttempt >= WIFI_RECONNECT_INTERVAL_MS) {
      lastReconnectAttempt = now;
      Serial.println("WiFi disconnected, attempting reconnect");
      WiFi.reconnect();
    }
    delay(500);
    return;
  }
  disconnectedAt = 0;

  if (!haveFetched || pressed || now - lastFetchAt >= FETCH_INTERVAL_MS) {
    lastFetchOk = fetchDisplay();
    lastFetchAt = now;
    haveFetched = true;
  }

  if (pressed || screensShown == 0 || now - lastScreenAt >= SCREEN_INTERVAL_MS) {
    lastScreenAt = now;
    showNextScreen();
  }
  delay(20);
}

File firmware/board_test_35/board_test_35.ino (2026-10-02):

// Bring-up test for the ESP32-32E 3.5" board (ST7796 320x480, XPT2046 resistive touch).
// 1. Color bars + text   -> the display works, colors are right
// 2. Wi-Fi + /api/display -> your watches from the Mac app, all on one screen
// 3. Touch               -> a dot where you touch; raw coordinates on Serial (115200)
//    Hold BOOT for ~1 s to run touch calibration (tap the 4 corner arrows); values print to Serial.
// Uses config.h (WIFI_SSID, WIFI_PASS, SERVER_URL), same as the watchbox_v0 sketch; LCD_ADDR is ignored.
#define LGFX_USE_V1
#include <LovyanGFX.hpp>
#include <WiFi.h>
#include <HTTPClient.h>
#include <ArduinoJson.h>
#include "config.h"

#ifndef COLOR_INVERT
#define COLOR_INVERT false
#endif
#ifndef COLOR_BGR
#define COLOR_BGR false
#endif

class LGFX : public lgfx::LGFX_Device {
  lgfx::Panel_ST7796 panel_;
  lgfx::Bus_SPI bus_;
  lgfx::Light_PWM light_;
  lgfx::Touch_XPT2046 touch_;

 public:
  LGFX() {
    {
      auto cfg = bus_.config();
      cfg.spi_host = HSPI_HOST;
      cfg.spi_mode = 0;
      cfg.freq_write = 20000000;  // 40 MHz garbled colors on this panel
      cfg.freq_read = 16000000;
      cfg.spi_3wire = false;
      cfg.use_lock = true;
      cfg.dma_channel = SPI_DMA_CH_AUTO;
      cfg.pin_sclk = 14;
      cfg.pin_mosi = 13;
      cfg.pin_miso = 12;
      cfg.pin_dc = 2;
      bus_.config(cfg);
      panel_.setBus(&bus_);
    }
    {
      auto cfg = panel_.config();
      cfg.pin_cs = 15;
      cfg.pin_rst = -1;  // shared with the ESP32 EN line
      cfg.pin_busy = -1;
      cfg.panel_width = 320;
      cfg.panel_height = 480;
      cfg.readable = true;
      cfg.invert = COLOR_INVERT;
      cfg.rgb_order = COLOR_BGR;
      cfg.bus_shared = true;
      panel_.config(cfg);
    }
    {
      auto cfg = light_.config();
      cfg.pin_bl = 27;
      cfg.invert = false;
      cfg.freq = 44100;
      cfg.pwm_channel = 7;
      light_.config(cfg);
      panel_.setLight(&light_);
    }
    {
      auto cfg = touch_.config();
      cfg.x_min = 300;  // typical XPT2046 raw range; calibration (BOOT) refines it
      cfg.x_max = 3900;
      cfg.y_min = 200;
      cfg.y_max = 3900;
      cfg.pin_int = 36;
      cfg.bus_shared = true;
      cfg.spi_host = HSPI_HOST;
      cfg.freq = 1000000;
      cfg.pin_sclk = 14;
      cfg.pin_mosi = 13;
      cfg.pin_miso = 12;
      cfg.pin_cs = 33;
      touch_.config(cfg);
      panel_.setTouch(&touch_);
    }
    setPanel(&panel_);
  }
};

LGFX tft;

// Measured on the owner's board (BOOT-held calibration, 2026-10-02).
uint16_t touchCal[8] = {378, 3815, 333, 301, 3689, 3781, 3687, 332};

const int BOOT_KEY = 0;
const uint32_t BG = TFT_BLACK;

void title(const char* text) {
  tft.fillScreen(BG);
  tft.setTextColor(TFT_WHITE, BG);
  tft.setFont(&fonts::FreeSansBold12pt7b);
  tft.setCursor(16, 14);
  tft.print(text);
}

void drawBars(int option) {
  const uint32_t colors[] = {TFT_RED, TFT_GREEN, TFT_BLUE, TFT_WHITE};
  const char* names[] = {"RED", "GREEN", "BLUE", "WHITE"};
  int w = tft.width() / 4;
  for (int i = 0; i < 4; i++) {
    tft.fillRect(i * w, 0, w, tft.height(), colors[i]);
    tft.setTextColor(TFT_BLACK, colors[i]);
    tft.setFont(&fonts::FreeSansBold12pt7b);
    tft.setCursor(i * w + 12, tft.height() / 2);
    tft.print(names[i]);
  }
  tft.fillRect(tft.width() / 2 - 40, 20, 80, 70, TFT_BLACK);
  tft.setTextColor(TFT_WHITE, TFT_BLACK);
  tft.setFont(&fonts::FreeSansBold24pt7b);
  tft.setCursor(tft.width() / 2 - 14, 30);
  tft.print(option);
}

void colorTest() {
  Serial.printf("color test: invert=%d bgr=%d\n", (int)COLOR_INVERT, (int)COLOR_BGR);
  drawBars(1 + (COLOR_INVERT ? 1 : 0) + (COLOR_BGR ? 2 : 0));
  delay(2500);
}

bool connectWifi() {
  title("Connecting to Wi-Fi...");
  WiFi.mode(WIFI_STA);
  WiFi.begin(WIFI_SSID, WIFI_PASS);
  unsigned long start = millis();
  while (WiFi.status() != WL_CONNECTED && millis() - start < 20000) delay(250);
  if (WiFi.status() != WL_CONNECTED) {
    title("Wi-Fi failed");
    tft.setFont(&fonts::FreeSans9pt7b);
    tft.setCursor(16, 60);
    tft.printf("status %d - check config.h (2.4 GHz)", WiFi.status());
    return false;
  }
  Serial.printf("WiFi connected, IP %s\n", WiFi.localIP().toString().c_str());
  return true;
}

void showWatches() {
  HTTPClient http;
  http.useHTTP10(true);
  http.setConnectTimeout(3000);
  http.setTimeout(5000);
  http.begin(String(SERVER_URL) + "/api/display");
  int code = http.GET();
  if (code != HTTP_CODE_OK) {
    title("Mac app not reachable");
    tft.setFont(&fonts::FreeSans9pt7b);
    tft.setCursor(16, 60);
    tft.printf("HTTP %d from %s", code, SERVER_URL);
    http.end();
    return;
  }
  JsonDocument doc;
  DeserializationError err = deserializeJson(doc, http.getStream());
  http.end();
  if (err) {
    title("Bad response");
    return;
  }
  JsonArray screens = doc["screens"].as<JsonArray>();
  tft.fillScreen(BG);
  int y = 12;
  bool first = true;
  for (JsonObject s : screens) {
    const char* l1 = s["line1"] | "";
    const char* l2 = s["line2"] | "";
    if (first) {  // TOTAL line, big and gold
      tft.setTextColor(0xFEA0, BG);
      tft.setFont(&fonts::FreeSansBold18pt7b);
      tft.setCursor(16, y);
      tft.print(l2);
      tft.setFont(&fonts::FreeSans9pt7b);
      tft.setTextColor(TFT_LIGHTGREY, BG);
      tft.setCursor(16, y + 44);
      tft.print(l1);
      y += 80;
      tft.drawFastHLine(16, y - 12, tft.width() - 32, TFT_DARKGREY);
      first = false;
      continue;
    }
    tft.setFont(&fonts::FreeSans12pt7b);
    tft.setTextColor(TFT_WHITE, BG);
    tft.setCursor(16, y);
    tft.print(l1);
    tft.setTextColor(TFT_GREENYELLOW, BG);
    tft.setTextDatum(top_right);
    tft.drawString(l2, tft.width() - 16, y);
    tft.setTextDatum(top_left);
    y += 40;
  }
  tft.setFont(&fonts::FreeSans9pt7b);
  tft.setTextColor(TFT_DARKGREY, BG);
  tft.setCursor(16, tft.height() - 24);
  tft.print("Touch anywhere - dots should appear under your finger");
}

void calibrate() {
  title("Touch calibration");
  tft.setFont(&fonts::FreeSans9pt7b);
  tft.setCursor(16, 50);
  tft.print("Tap each arrow as it appears");
  delay(1200);
  uint16_t cal[8];
  tft.calibrateTouch(cal, (uint32_t)TFT_WHITE, BG, 20);
  Serial.print("Touch calibration: {");
  for (int i = 0; i < 8; i++) Serial.printf("%u%s", cal[i], i < 7 ? ", " : "}\n");
  tft.setTouchCalibrate(cal);
  showWatches();
}

void setup() {
  Serial.begin(115200);
  pinMode(BOOT_KEY, INPUT_PULLUP);
  Serial.println("init display");
  tft.init();
  Serial.println("display ok");
  tft.setRotation(1);
  tft.setTouchCalibrate(touchCal);  // landscape, 480 x 320
  tft.setBrightness(200);
  colorTest();
  if (connectWifi()) showWatches();
}
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

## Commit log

2026-09-28 Add Watch Box prototype v0 design spec
2026-09-28 feat: price filtering and median summary
2026-09-28 fix: review fixes for pricing, db and display
    - pricing.py: listing_matches now returns False for an empty/blank
    reference instead of matching every title.
    - pricing.py: JUNK_PHRASES replaces the bare "manual"/"repair" words
    with specific phrases (instruction manual, manual only, for repair,
    needs repair, repair only) so manual-wind watches aren't misflagged.
    - display.py: time_ago now treats a naive ISO timestamp as UTC instead
    of raising when subtracted from an aware "now".
    - db.py: update_watch performs the UPDATE and the conditional price
    DELETE in a single transaction (one commit), keeping the existing
    SlotTakenError mapping.
    - Added regression tests for all of the above, pl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
2026-09-28 feat: I2C scan sketch for LCD bring-up
    Also update Task 10 Step 1 with direct-download instructions for
    arduino-cli, since Homebrew is not available in this environment.
2026-09-28 feat: ESP32 LCD firmware for WatchBox v0
2026-09-28 fix: firmware review fixes (button edge, WiFi watchdog, HTTP hardening)
    - Button: trigger only on HIGH->LOW transition passing the 300 ms
    debounce, so holding the button registers as one press.
    - WiFi watchdog: restart if initial connect doesn't complete within
    60 s (logging status while waiting); in loop(), attempt
    WiFi.reconnect() once per 30 s while disconnected and restart after
    5 minutes disconnected.
    - fetchDisplay: use HTTP/1.0, add a 2 s connect timeout and 3 s
    response timeout, and reject a response whose "screens" field isn't
    a JSON array before overwriting the screens buffer.
    Updated the plan's Task 11 code block to match, and added hardware
    notes (5V I2C pull-ups vs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
    [watchbox_v0.ino]
2026-09-28 feat: parametric enclosure for WatchBox v0
    [watchbox_v0.scad, watchbox_v0_back.stl, watchbox_v0_front.stl]
2026-09-28 fix: enclosure fit and README hardware notes
    [watchbox_v0.scad, watchbox_v0_back.stl, watchbox_v0_front.stl]
2026-09-29 feat: use TheWatchAPI's newest price even when old, and show its date
    TheWatchAPI's history currently ends 2024-07-17, so drop the 30-day window,
    store the data date per price (migrating older databases), show it on the
    web page, and add the month to the LCD line when the data is over 30 days old.
2026-09-29 feat: enclosure sized to measured LCD and ESP32
    Measured: LCD frame 71 x 24.44, 18 mm total LCD depth (backpack 9.4 mm),
    backpack with side connectors 61 mm, ESP32 50 x 27. Adds lcd_side_room (20 mm)
    for the sideways connectors. Outer size 124.6 x 54.6 x 51.6 mm.
    [watchbox_v0.scad, watchbox_v0_back.stl, watchbox_v0_front.stl]
2026-10-02 feat: listing detail parsers and junk filter
2026-10-02 feat: valuation service wired in as the comps price source
2026-10-02 feat: widen thin detail matches and adjust for dial/bracelet
    Tier 1 (owner's dial/bracelet) only wins if it keeps >=5 of each well-covered
    source; otherwise tier 2 is used with learned dial/bracelet factors (shrunk
    toward 1.0, clamped 0.85-1.20). Datejust 126334 blue: 7 -> 52 comparables,
    backtest error 16.4% -> 9.5%.
2026-10-02 feat: lid liner for the 3.5" ESP32 display board
    Fills the heavy-duty case lid (measured from obj_3_top.stl), seats 12.5 mm
    above the lid floor on taped legs, frames the touch area, holds the board on
    4 posts, battery bay and cable notches; collision-checked against the lid.
    Includes a quick fit-test coupon.
    [lid_liner.scad, lid_liner.stl, lid_liner_coupon.stl]
2026-10-02 feat: bring-up test sketch for the ESP32-32E 3.5" board
    Color bars, Wi-Fi + /api/display rendered on one screen, touch dots and
    BOOT-held touch calibration (LovyanGFX, ST7796 + XPT2046).
2026-10-02 fix: 3.5" board test at 20 MHz SPI with measured touch calibration
    40 MHz garbled colors on this panel; normal color order/inversion is correct.
    [board_test_35.ino]
